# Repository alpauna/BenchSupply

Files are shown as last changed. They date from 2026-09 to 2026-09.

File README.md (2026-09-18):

# BenchSupply

A printed box for the bench supply that feeds the ECU and the VR test rig:
screw-down lid, 40 mm fan at one end, exhaust grid at the other, and a fused
IEC C14 inlet/switch module on the end wall beside that grid, its terminals
under a printed shield. A small **two-rail DC-DC module** has the long wall to
itself, fed from the 36 V supply inside — its fixed 5 V runs the
VR rig's Pico, its adjustable rail is a bench output.

**Forked from [`TritonECU/hardware/psu-enclosure`](../TritonECU/hardware/psu-enclosure) — this is the copy to grow.**
The two are still identical geometry: the DC-DC landed in **both**, because it
is part of the working box rather than speculative growth. `psu-enclosure` is
the version that stays printable; changes for the wider bench live here, so the
working enclosure is never in pieces. Diverge freely — from here on, expect to.

> **The supply this box was built around is being replaced.** It is going to a
> **toroidal transformer** and two isolated 2–60 V / 3 A channels, which is a
> different machine: two 2.9 kg toroids instead of one light switcher, ~100 W of
> heat instead of a warm box, and 5.8 A of mains with the inrush of two 350 VA
> transformers. **Do not print the tub from this file expecting it to hold that.**
> The reasoning is in [`docs/power-chain.md`](docs/power-chain.md), the control
> electronics and cooling in [`docs/control.md`](docs/control.md), and the
> schematics in [`design/`](design/);
> everything below still describes the box as drawn, which is correct for the
> old supply.

**This box contains mains wiring.** Read [Safety](#safety) before energising it.

## Room already in it

The box was sized generously on purpose. **The DC-DC is the first thing to take
any of that slack**, and it took less than it looks: 84 mm of the bay wall, and
depth only where its boss steps out.

| Where | Free space | Good for |
|---|---|---|
| Bay wall, between DC-DC and gland | **60 mm** of flat wall (x 106–166) | the largest unbroken panel span |
| Bay wall, past the gland | **90 mm** (x 194–282) | the mains has left this wall entirely — it is all low voltage now |
| Bay wall, END A end | 19 mm before the DC-DC | small stuff only |
| Front bay, volume | **50 mm** wide × 279 long, less the DC-DC's 84 | terminal blocks, DC distribution |
| Back bay | **34 mm** × 279, less the shield's 44 in the middle | **mains only** — keep it that way |
| Over the supply | 2 mm to the rim taper, 17 mm to the lid | nothing tall — raise `head` if you need a shelf |
| Fan-end plenum | 10 mm × 195 × 98 | the air path. Do not fill it |
| The lid | untouched | a flat 285 × 243 plate; panel-mount anything to it |
| END A | the LV gland only | the rest of that wall is the fan and the plenum |
| END B | exhaust grid only | the inlet left; the bay corners either side of the grid are free again |

**A buck module for the fan is no longer on that list** — the DC-DC covers the
role, but *not* on its adjustable rail. See [The fan is not a load for the
adjustable rail](#the-fan-is-not-a-load-for-the-adjustable-rail).

The honest constraint is **height**, not floor area. `head` is 2 mm, so there is
no usable layer above the supply until you raise it — and every mm you add there
adds a mm to the outside.

**The X growth cap has moved.** This was written against a 300 bed, which put
the ceiling at about 290 including the pads — right where the tub already sits.
The printer is now a **QIDI X-Plus 5: 320 × 320 × 300**, read from
`Qidi X-Plus 5 0.4 nozzle.json` in QIDIStudio 02.07.02.60. Against the tub's
current 294 × 243 that is **26 mm spare in X and 77 in Y**, so X is no longer
the axis that stops you — height still is, and it is the one axis the bed does
not help with.

```
                 TOP VIEW  (285 long)

     END A                                      END B
   +-------------------[ PLUG ]-----------------------+  <- BACK: mains only
   |                   [shield]        34 mm bay      |
   |--------------------------------------------------|
   |[FAN]                                       ######|
   |         power supply  266 x 153 x 77       ######|  <- exhaust grid
   |   intake -->  air over and under  -->  out ######|
   |--------------------------------------------------|
   |(LV)                               50 mm bay      |
   +--------[ DC-DC ]------------[GLAND]--------------+  <- FRONT: low voltage
             5 V + adj            36 V out
```

**Mains on the back wall, low voltage on the front.** The inlet is centred
because **a toroidal transformer sits either side of it**, so the primary leads
reach it from both without crossing. END B is nothing but exhaust grid now.

The mains lives on the **back wall only** — inlet centred, its terminals inside
a printed shield that stands on the floor. The front wall is all low voltage:
see [the inlet and its
shield](#the-inlet-is-on-the-back-wall--and-brought-a-shield).

## Dimensions

| | |
|---|---|
| External | **285 × 243 × 109** mm |
| Bed footprint, tub | **294 × 243** — the fan pad stands proud of END A, the plug pad off the back wall |
| Bed footprint, lid | 285 × 243 |
| Clear space for the supply | **279 × 156 × 79** (the 266 × 153 × 77 minimum, with room) |
| Wiring bays | **back 34 mm** (mains only), **front 50 mm** (low voltage, clear end to end) |

`openscad` echoes all of these on every render, so they follow the parameters
rather than this table. Re-read them after changing anything.

**The tub needs a genuine 300 × 300 bed**, with 5 mm to spare on each side in X.
Print it with a *skirt*, not a brim — a brim will not fit. If your printer
cannot reach 290, drop `clr_fan` from 10 to 6 and re-render; you lose plenum
depth at the fan and nothing else.

## Measure these before printing

The `.scad` is parametric but it cannot guess:

```
psu_l, psu_w, psu_h    the supply's real outside dimensions
standoff_xy            the supply's mounting-foot pattern
mod_cut_w/h, mod_depth the DC-DC module's body, and how far it stands behind
mod_flange, mod_lock_w its bezel lip and its snap locks
mod_boss               which is a DECISION, not a measurement — see below
```

The supply's dimensions default to the 266 × 153 × 77 minimum. **The foot
pattern has no default worth trusting** — there is no standard for it. The six
standoffs as shipped are *pads*: they hold the supply 4 mm off the floor so air
can get under it, and that is all they do. Measure the feet, edit
`standoff_xy`, then set `standoff_hole = true` to get M4 clearance holes with
head recesses on the underside of the floor.

The `mod_*` defaults are the module actually in hand — **64 × 38.5 × 25.4 behind
a 4 mm flange, with two 12.7 mm snap locks centred on the vertical edges.**
Measure yours. Every clearance on that wall that was tight enough to be worth
arithmetic is an `assert` in the `.scad`, so a wrong number stops the render
rather than the print.

## Bought parts

| Qty | Item | Notes |
|--:|---|---|
| 1 | **40 × 40 × 10 mm fan**, 12 V | 32 mm bolt centres, Ø3.5 holes — the WINSINN drawing |
| 1 | **IEC C14 inlet + rocker + fuse module** | BIQU 10 A 250 V; 58 × 48 face, 50 × 29 × 19 rear flange, M3 ears at 40 mm |
| 1 | 5 × 20 mm fuse | size it to the supply, not to the socket's 10 A rating |
| 10 | **M3 × 12 socket head** | lid |
| 4 | **M3 × 10 self-tapping** | fan, through its own Ø3.5 holes into the pad |
| 2 | **M3 × 12 self-tapping** | plug ears, into the 7 mm pad |
| 4 | M4 × 10 | supply feet, *once you have measured them* |
| 1 | **PG7 cable gland** or Ø12.5 rubber grommet | 36 V DC output, bay wall |
| — | 16–14 AWG wire + insulated spade terminals | the inlet module ships with a set |
| 4 | Stick-on rubber feet | the floor is flat by design |
| 1 | **DC-DC module, two rails** — fixed 5 V + LCD-set adjustable | 64 × 38.5 face, 25.4 deep, 4 mm flange, snap-lock mount. **40 V DC input rating** — confirmed, against a 36 V bus. See below |
| 1 | **Fuse + holder, 1–2 A**, inline | the 36 V tap to the DC-DC. *Not optional* — see below |
| 1 | **PG7 cable gland** or Ø12.5 grommet | low-voltage output, END A wall |
| 1 | **Schottky, 1 A** (1N5819 or similar) | in the 5 V feed to the Pico's `VSYS` |
| — | 20–22 AWG wire, **two colours** | the 5 V pair and the adjustable pair, kept tellable apart |
| 2 | **M3 × 10 self-tapping** | the mains shield, into its two floor posts |

## Printed parts

| Qty | Part | Orientation |
|--:|---|---|
| 1 | `tub` | **floor down**, open side up |
| 1 | `lid` | **outer face down** — see below |
| 1 | `shield` | **on its back** — the flat face that carries the wire slot, down on the bed |
| 1 | `psu5_shell` | **face down** — the grid face flat on the bed, so no wall overhangs |

**Print the lid upside down, outer face on the bed.** Modelled ribs-down as it
sits on the box, so flipping it makes every rib and the locating ring grow
*upward*. Nothing then overhangs except a 1.5 mm annular bridge over each screw
counterbore, which any printer manages. Printed the other way up, four ribs and
a 250 mm ring are all overhang.

**PETG or ABS, not PLA.** This one is not about stiffness — it is that the box
holds a warm supply and a mains connection, and PLA softens at temperatures a
loaded supply reaches in a closed box.

Walls are 3 mm, **the floor is 6** — see below. 3 perimeters and 25 % infill is
plenty. The lid wants **4 perimeters** so the screw counterbores have solid
material around them.

### The floor is doubled, and not for strength

5.8 kg of toroidal transformer is not a lot of load — even a 3 mm floor only
sees **2.6 MPa** against PETG's ~50 MPa yield. Stress was never the problem.
**Deflection is:**

```
   t          D   deflection    stress
  3mm      5357       2.13 mm    2.62 MPa
  6mm     42857       0.27 mm    0.65 MPa
  8mm    101587       0.11 mm    0.37 MPa
```

A 3 mm floor bows **2.1 mm** under its own occupants, and a box standing on four
rubber feet rocks on that. Worse, PETG creeps, so whatever it bows settles in
permanently — and a box shedding ~100 W runs warm, which speeds creep up.

Doubling to 6 mm is **8× the stiffness** (t³) and a quarter of the stress
(1/t²), for 0.27 mm. It costs ~200 cm³ of envelope — call it 130–250 g
depending on infill — and 3 mm of height. [`docs/calc/floor.py`](docs/calc/floor.py)
has the arithmetic and a sensitivity sweep, because printed PETG's modulus is
not a datasheet number.

**What 6 mm does not fix: the bolt.** Each toroid still hangs off one central
screw, and a screw in plastic is a bearing problem, not a bending one. **Put a
steel spreader under the floor** — a large washer at minimum, better a plate.

## How it is put together

### The lid seat is a rim band, not corner posts

With 3 mm of clearance beside the supply there is nowhere to put a corner post —
it would land inside the supply. So the screws go into a band that thickens the
wall inward around the whole top rim, sitting **entirely above the supply**
where the volume is free anyway. It costs 17 mm of height and no floor area.

The band's underside is a 45° taper (`rim_taper = rim_w`, keep them equal), so
it prints with no support and leaves no drooping ledge over the supply. Its
inner face is the rabbet the lid's locating ring drops into, which is what stops
the lid sliding and closes the dust gap.

Ten M3s: four along each long wall, one at each end.

### The fan mounts outside

Inside would cost 10 mm of a 10 mm plenum, and the supply is only 10 mm away.
The pad on the outside also gives the M3s **8 mm of plastic** to cut into
instead of 3.

**Mount it as an intake** — airflow arrow and label pointing *into* the box. Air
enters at END A, splits between the 4 mm gap under the supply and the space over
it, and leaves through the grid at END B. Blowing the length of the supply is
the whole reason the fan and grid are on opposite ends rather than opposite
sides. Run the fan off the supply's own DC output if the voltage matches, or off
a small fixed buck of its own — **not** off the DC-DC's adjustable rail, for the
reason in [The fan is not a load for the adjustable
rail](#the-fan-is-not-a-load-for-the-adjustable-rail).

### The grid is diamonds, not squares

A square hole in a vertical wall has a flat top edge that has to bridge. A
diamond has an apex, so every one of the 78 holes is self-supporting and nothing
droops into the airstream.

### The bay is still why things fit — just not the plug any more

The bay was originally sized by the inlet: its rear flange stands **19 mm**
proud of the panel, the spade terminals and their boots add more, and none of
that can happen on the wall the supply is pressed against. So a channel ran down
one long side.

**The inlet has since moved to the back wall**, and the front bay stayed — two other
things now need it. The DC-DC is 25.4 mm deep behind its panel, and the mains
shield is 44 mm wide. The shield is the binding one: 29 mm of flange, clearance
for booted spades either side, a wall each side, and a 39 mm bay cannot hold it
at any sane wall thickness.

At **50 mm** the shield fits with 3 mm a side, and the DC-DC gets 24.6 mm behind
it on a flat wall — so `mod_boss` went to **0** and the bump on the outside of
that wall disappeared. The box grew 11 mm in Y and lost a 12 mm boss, and the
plug pad moved from the Y face to the X face: **the bed footprint went from
290 × 213 to 294 × 212 at that point, which was no change worth the name.**
(The back bay has since taken it to 294 × 243 — see the inlet section.)

`gland_x` is a parameter. Slide it along the wall to land beside the supply's
own DC output terminals. The shield no longer competes for this bay at all —
it moved to the back with the inlet — so the front wall is clear end to end.

## The inlet is on the back wall — and brought a shield

### The back wall was blank because it had no depth

That wall had nothing on it, which is exactly why it was the one to use — and
exactly why it could not be used as drawn. The supply sat **3 mm** behind it,
and 12 mm of intruding flange plus 12 mm of booted terminals does not go in
3 mm. `bay_back` is what buys the room: **34 mm**, which leaves 2.5 mm between
the shield and the supply.

**It is cheaper on this wall than it was at END B.** There the shield's 44 mm
*width* had to fit across the bay, so the bay had to be 50. On a long wall the
width runs along the wall, which is free, and only the 31.5 mm of depth costs
anything. The box went 212 → **243** in Y for it, and the bed footprint to
294 × 243 — comfortable on a 320 bed.

What it buys back: the mains now has a wall to itself, the front wall is all
low voltage — the DC-DC's screen and knob, the outputs — and **END B is nothing
but exhaust grid**, which is better for the air than having a shield parked in
the bay at the hot end.

`plug_x` is centred, and stays centred: **a toroid sits either side of it.**

### And it sits low, which is the shield's doing

The shield **stands on the enclosure floor** and uses that floor as the fourth
side of its wire slot. That only works if the terminals are near the floor, so
`plug_z` is **36**, putting the flange between z 11 and 61 and leaving 8 mm of
shield underneath for the wires to turn in.

It is still mounted **58 mm axis vertical**, so the rocker is at the top and the
fuse drawer pulls out below it. The pad is a slab on the *outside* of the back
wall, so `plug_pad_w` has to stay within the wall's length or it hangs in
mid-air with nothing behind it — the `.scad` asserts that, though with 285 mm of
wall and a 54 mm pad there is no danger.

### The shield: two open faces, and a slot that is open at the bottom

The inlet's spade terminals are exposed mains. With the lid off they are a
finger away. The shield covers them.

**They are no longer the only exposed mains.** The 5 V control module is an
open-frame board — live AC terminals and a live primary side on a bare PCB. It
needs the same treatment; see [`docs/control.md`](docs/control.md#it-is-open-frame--so-it-needs-a-cover-too).

It is a cup with **two open faces**: the one against the END B wall, where the
inlet comes through, and the **bottom**, where it stands on the floor.

**The wire slot is the whole point of the shape.** The three spades are crimped
and booted *before* the shield goes anywhere near them, so the wires cannot be
threaded through a closed hole — a closed hole would mean stripping the
terminals off again to fit the cover. So the slot runs off the bottom edge of
the back wall: **three of its sides are printed into the shield, and the fourth
is the enclosure floor** once the shield is screwed down. Lay the booted wires
in, drop the shield over them, put two screws in.

The slot is **26 × 14**, which takes three booted spades side by side.

### Assembly order matters now

**Fit the inlet and drive its two ear screws before the shield goes on.** The
shield covers the back of the inlet completely; once it is down, those screws
are unreachable without taking it off again. Same for the spade terminals —
crimp, boot and seat them all first.

### Print it on its back

Laid with the slotted back face on the bed, every other wall of the shield is
perpendicular to the bed. **There is not one overhang in the part** — no
supports, no bridges, and the slot comes out as a clean rectangular notch rather
than a sagging hole.

## The second supply — a DC-DC module, not a second mains supply

The box gained a second output stage: a two-rail DC-DC with an LCD, panel
mounted at the END A end of the bay. **It is fed from the 36 V supply already in
the box, not from the mains.** That is what makes it a cheap addition — no
second inlet, no second cord, and no more live terminals in a box that already
has a set. Everything it does still sits downstream of the C14's fuse.

| rail | what it is for |
|---|---|
| **fixed 5 V** | the VR rig's Pico, and the DM542's `PUL+ / DIR+ / ENA+` commons |
| **adjustable** | set from the LCD; a bench rail, out through the same gland |

### 40 V in, on a 36 V bus — which makes it the weakest part on that bus

**The module is rated 40 V DC in.** Against 36 V that is 4 V of headroom, about
11 %, and in steady state it is fine: an open-frame supply regulates to a
percent or so and never goes near the ceiling. (Worth saying because most
modules this size stop at 32 V, which this supply would destroy on the first
switch-on. This one clears it.)

What the rating changes is *which part fails first*. The DM542 is rated **50 V**.
The DC-DC is rated **40**. **The lowest-rated thing on the 36 V bus is now the
supply the Pico runs on** — so an excursion that used to threaten only the
driver now takes out the 5 V rail first, and the step generator with it.

That excursion is already documented: [ramp the
decelerations](../TritonECU/hardware/vr-test-rig/BOM.md#ramp-the-decelerations--capacitance-cannot-fix-a-hard-stop).
A switching supply cannot sink current, so a hard stop dumps the wheel's energy
into whatever capacitance is on the bus and drives it to 64–120 V. That ramp was
load-bearing before. It is more so now, against a ceiling 10 V lower.

Two things follow:

- **Do not touch the supply's V-ADJ trimmer.** Open-frame supplies commonly trim
  ±10 %, and +10 % of 36 is **39.6 V** — 0.4 V from the module's absolute
  maximum, before any transient at all.
- The 1000 µF at the driver's `V+` is now insurance for the DC-DC as well as for
  the driver. Fit it.

#### And a TVS cannot cover the gap

The reflex is to clamp the bus. It does not work here, and the reason is
arithmetic rather than taste: the part would have to stand off 36 V without
conducting **and** clamp below 40 V, and nothing does both. The lowest standard
device that stands off 36 V is an `SMBJ36A` — breakdown **40.0–44.2 V**,
clamping at **58.1 V**. Its breakdown tolerance alone is wider than the whole
4 V margin: at one end of the spread it begins conducting at the module's
ceiling, and it does not clamp hard until 18 V past it.

The window between 36 V working and 40 V absolute maximum is too narrow for a
transient suppressor to live in. **The ramp is the mitigation; there is no
component to buy instead.**

### Fuse the tap

The 36 V supply will put **10 A into a fault** and has no idea it is a fault.
Put a **1–2 A fuse in the tap**, at the supply's terminal end so it protects the
wire and not just the module. The C14's fuse is sized for the whole supply and
will never notice a shorted DC-DC — which is a fault inside a plastic box.

### The Pico goes on `VSYS`, not `VBUS`

The Pico's **`VBUS` pin is the USB connector's 5 V, directly.** Feeding it means
back-feeding the host's USB port. Use **`VSYS` (pin 39)**, with GND on pin 38 —
that is what the datasheet provides for exactly this. USB reaches `VSYS` through
the on-board Schottky `D1`, so a cable can stay plugged in for programming: `D1`
reverse-blocks and nothing flows back into the port.

Put a **Schottky in the feed** as well, so the module is protected in the other
direction too. 5 V less the drop lands `VSYS` near 4.7 V, comfortably inside its
1.8–5.5 V range.

The part that is an *improvement* rather than a change: `PUL+ / DIR+ / ENA+`
come off this same 5 V rail. [The VR rig BOM](../TritonECU/hardware/vr-test-rig/BOM.md) used to
take them from the Pico's `VBUS`, which meant **the driver's opto commons died
the moment the USB cable was unplugged.** On this rail they do not.

The module's 5 V return, the Pico's GND and the 2N7002 sources are one node.
Run the 5 V and its return out as a **pair**.

### Star the ground — it is no longer floating

The optos were never isolating the Pico from the motor supply in the first
place: `PUL+` and `PUL−` are both in the Pico's domain and the barrier is inside
the driver. What changes is the **reference**. A non-isolated buck ties the
Pico's ground to the 36 V supply's negative, which is also the DM542's return —
and 2 A/phase of chopper current flows in that return.

So take the module's input **from the supply's own output terminals**, not
daisy-chained off the DM542's `V+ / V−` screws. Then the motor's return current
never flows through a conductor the Pico's ground shares, and the ripple stays
where it belongs.

One consequence worth knowing about: with the Pico's ground tied to the supply
negative, a USB cable to a PC now joins the PC's ground to it as well. That path
did not exist before.

### The fan is not a load for the adjustable rail

Tempting — the fan wants 12 V, this page used to hand-wave "a small buck module
in the bay", and there is now a rail in the bay that can be set to 12.
**Don't.** It would put the cooling on a knob, in a box whose airflow depends
entirely on that fan and which holds a warm supply and a mains connection. Give
the fan its own fixed source and leave the adjustable rail free.

### Label the two pairs at the gland

Two wire pairs leave the same gland and one of them can be at 30 V. **Two
colours, and a label at both ends.** Swapping them puts the adjustable rail on
the Pico's `VSYS`.

### It sits in still air

The fan blows END A to END B *over and under the supply*; the bay is off to one
side and barely sees it. At the load this rail was added for — a Pico and three
optos, call it 100 mA at 5 V, well under a watt — that does not matter. Start
pulling amps from the adjustable rail and the module wants a heatsink, because
the bay will not cool it.

## How the DC-DC is mounted

### It hangs on its own snap locks

Two tapered locks, one on each **vertical edge** of the cutout, 12.7 mm long,
centred. They start about 1 mm behind the bezel and taper back 3, so they grip a
panel **1 to 4 mm thick**. A 3 mm wall is right at the far end of that taper —
a loose grip on a module standing 25 mm off the panel — so the panel is
**thinned to 2 mm** over a patch reaching 6 mm past the cutout all round.

That relief is cut on the **inside** face. The outside stays flat, so the bezel
lands on plain wall and none of it shows.

Nothing else holds the module: no screws, no brackets. The cutout's left and
right edges are the only surfaces carrying it, so keep them clean and do not put
anything else on them. Printed floor-down they are vertical walls and come out
crisp — but test-fit the module before you wire anything to it.

### The panel is flat — the boss is gone

It was not always. When the inlet shared this wall the bay was 39 mm, the module
is 25.4 deep, and that left 13.6 mm for its terminals and the bend in the wire —
not enough if they exit straight back, which on these modules they usually do.
The panel sat on a boss that stepped **12 mm outward** to buy 25.6 mm.

Moving the inlet to END B forced the bay to 50 for the shield, and **50 − 25.4
is 24.6 mm on a flat wall** — as much as the boss ever bought. So `mod_boss` is
**0**, the bump is gone, and the long wall is flat from end to end.

Raise `mod_boss` again if you ever narrow the bay; the geometry is still there
and still drafted at 45°. The render asserts you have left enough room either
way.

### Why END A, and why the output leaves on the end wall

Three things now share the bay wall, and the order is deliberate: **low voltage
at END A, mains in the middle, 36 V DC at END B.** The DC-DC's output gland is
on the **END A wall**, not the bay wall, so the 5 V and adjustable pairs never
run the length of the bay toward END B, where the mains now is.

`mod_x` slides the module along the wall as `gland_x` does — and the `.scad`
asserts it clears both the gland and the ends, so a bad value stops the render.

## Safety

The box is plastic, so there is nothing to bond to earth — but the C14's earth
pin still has to go somewhere. **Run it to the supply's earth terminal.** Do not
leave it unconnected because the enclosure is non-conductive; the supply's
chassis and its output reference need it.

- The lid screws are the only thing between a finger and 120 V. Fit all ten.
- Fuse for the *supply*, not for the socket. The inlet module is rated 10 A;
  that is a ceiling, not a recommendation.
- Use the insulated spade terminals the inlet module ships with, fully seated.
- Fit the cable gland or grommet before pulling the DC output wires through. A
  bare printed hole will cut insulation over time, and the layer lines make it
  worse than a drilled one.
- Strain-relieve the mains wiring inside the bay so a tug on the cord cannot
  reach the terminals.
- **Fit the shield.** It is the only thing between a finger and the inlet's
  terminals once the lid is off, and it is two screws. Fit the inlet and drive
  its ear screws *first* — the shield covers them.
- **Fuse the DC-DC's 36 V tap at 1–2 A.** A shorted module on a 10 A supply is
  an ignition source, and the C14 fuse is far too big to see it.
- Keep the DC-DC's wiring at the END A end of the bay, clear of the inlet's
  spade terminals. That separation is why the module and its gland are where
  they are; do not undo it by routing the low-voltage pairs past the plug.

## Rendering

```bash
./render.sh          # all three parts to stl/
```

Or one at a time:

```bash
openscad -D 'part="tub"' bench_supply.scad
openscad -D 'part="lid"' bench_supply.scad
openscad -D 'part="shield"' bench_supply.scad
```

`part = "assembly"` (the default when you open the file) shows the tub, the lid
in place, the shield in **red**, and **ghosts** of the supply, the fan, the
DC-DC and the inlet. The inlet ghost is the one to look at: its terminal block
is what the shield has to swallow, and what sets the bay width.

STL export is not byte-deterministic — rendering the same unchanged file twice
produces different files. **`bench_supply.scad` is the source of truth**; the
STLs are a convenience so the parts can be printed without installing OpenSCAD.
Re-run `render.sh` after any change and do not read anything into the diff.

## Parameters worth knowing

| Parameter | Default | What it moves |
|---|--:|---|
| `psu_l/w/h` | 266/153/77 | everything — **measure yours** |
| `standoff_xy`, `standoff_hole` | pads, off | the supply's foot pattern |
| `clr_fan` | 10 | plenum depth at the fan end, and total length |
| `bay_w` | 50 | wiring channel; the **shield** needs most of it now |
| `rim_w`, `rim_taper` | 6, 6 | lid seat. **Keep them equal** — that is the 45° |
| `boss_d` | 9 | lid screw engagement. Heat-set inserts? 7 is enough |
| `lid_screw` | 2.6 | M3 self-tapping pilot. Heat-set M3 insert: **4.2** |
| `fan_guard` | true | concentric webs over the fan bore |
| `plug_x`, `plug_z` | **centre**, 36 | where the inlet lands on the back wall. Centred for the toroids either side; low so the shield reaches the floor |
| `gland_x` | −105 | where the 36 V output leaves the bay wall |
| `bay_w` | **50** | front bay — low voltage. Set by the DC-DC now |
| `bay_back` | **34** | back bay — mains only. Set by the shield's depth |
| `sh_clr`, `sh_wall` | 5, 2.5 | shield clearance round the terminals, and its wall |
| `sh_notch_w/h` | 26, 14 | the wire slot. Its fourth side is the floor |
| `sh_tab_z` | 20 | screw tabs, high enough to clear the slot |
| `grid_pitch`, `grid_sq` | 10, 6 | exhaust open area |
| `mod_cut_w/h`, `mod_depth` | 64/38.5, 25.4 | the DC-DC's body — **measure yours** |
| `mod_boss` | **0** | how far the DC-DC's panel steps out. 0 = flat wall; changes the box |
| `mod_panel_t` | 2.0 | panel at the cutout. The snap locks grip 1–4 |
| `mod_x` | 64 | where the DC-DC lands along the bay wall |
| `mod_relief_m` | 6 | how far the thinned panel reaches past the cutout |

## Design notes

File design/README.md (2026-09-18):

# design

Schematics and BOMs. The reasoning behind every value is in
[`../docs/power-chain.md`](../docs/power-chain.md) and
[`../docs/control.md`](../docs/control.md); the scripts in `../docs/calc/`
reproduce the numbers.

| board | qty | schematic | BOM |
|---|--:|---|---|
| Mains entry, distribution, soft start | 1 | [`schematic-mains.txt`](schematic-mains.txt) | [`bom-mains.csv`](bom-mains.csv) |
| Rectifier and bulk | **2** | [`schematic-rectifier.txt`](schematic-rectifier.txt) | [`bom-rectifier.csv`](bom-rectifier.csv) |
| LT8705 converter | **2** | [`schematic-converter.txt`](schematic-converter.txt) | [`bom-converter.csv`](bom-converter.csv) |
| Control - Pico, fans, sensors, UI | 1 | [`schematic-control.txt`](schematic-control.txt) | [`bom-control.csv`](bom-control.csv) |

One mains board. One rectifier and one converter **per channel**.

## Before you draw any of it

**The LT8705 pin names in the converter schematic are functional, not
transcribed.** Check them and the pin numbers against the datasheet. That
document is the design intent.

**Confirm Qg on whichever FET you buy.** It is the binding parameter — at 60 V
switching loss beats conduction loss, so a 10 mΩ part carrying 150 nC loses to
a 25 mΩ part carrying 40 nC — and it is the number least reliably quoted in
distributor listings.

**Verify the ADG714 powers up with all switches open.** That is the fail-safe
direction: switches open is 2 V out, and it has to hold when the isolated side
is unpowered, in reset, or being reflashed.

## Three things in here that are structural, not preferences

Each survives a component failure, a firmware hang, or a reflash. None of them
should be "simplified" later without understanding what it is buying.

**The fixed divider branch sets 2 V and the switches only add.** Switches open —
unpowered, in reset, mid-reflash — is minimum output. Wired the other way round,
every one of those states commands 60 V into whatever is connected.

**`RLY_SOFT` is a one-shot, not a level.** It drops out by itself whether or not
`RLY_MAIN` closed, so the 10 Ω soft-start resistor can only ever be in circuit
for one monostable period. Without that, a relay that fails to close leaves it
at 85 W indefinitely.

**TS1 sits in parallel with fan 1's drive FET.** All three fans are staged by
the Pico, and a thermostat closes at 65 °C regardless — so a box shedding 108 W
with no fans because the Pico is halted, or because someone is reflashing it,
cannot happen. Hardwiring fan 1 on would also prevent it, and would throw away
useful control to do so.

## Where the optocouplers live

**On the converter boards, not on the control board.** Every signal leaving the
control board is Pico-referenced, including the LED drive going out and the
phototransistor collector coming back — the isolation happens at the far end.

Put them on the control board instead and it would carry **three** isolated
domains — Pico, channel A, channel B — with barrier slots between them. There is
no reason to.

## What is not here yet

Nothing. All four boards are drawn. What remains before layout is the
[layout spec](../docs/) — net classes, trace widths, hot-loop targets — and
confirming the three items above.

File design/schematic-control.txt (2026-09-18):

BENCH SUPPLY - CONTROL BOARD
Pico, the barrier drive, fan staging, sensors, relay sequencing
===============================================================================

  ** THE OPTOCOUPLERS ARE NOT ON THIS BOARD. **

  They live on the converter boards, one set per channel. That is deliberate
  and it is what keeps this board simple: every signal leaving here is
  referenced to the Pico's ground, including the LED drive going out and the
  phototransistor collector coming back. The isolation happens over there.

  Put the optos here instead and this board would carry THREE isolated
  domains - Pico, channel A, channel B - with barrier slots between them.
  There is no reason to.

  So: ONE ground domain on this board. The 5 V module feeds it, and the
  module's own transformer is what isolates the whole thing from mains.

1. GPIO BUDGET - CHECK THIS BEFORE ADDING ANYTHING
--------------------------------------------------

  SPI0 to channel A: SCK MOSI MISO CS_SW CS_AD     5
  SPI1 to channel B: SCK MOSI MISO CS_SW CS_AD     5
  RLY_MAIN drive x2                                2
  NE556 trigger x2 (the RLY_SOFT one-shots)        2
  fan 1, fan 2, fan 3 drive                        3
  1-Wire bus (3 sensors)                           1
  display, I2C                                     2
  encoder A: A B push                              3
  encoder B: A B push                              3
  --------------------------------------------------
  TOTAL                                           26   of 26. NONE SPARE.

  Driving fan 1 costs the last pin.

1a. THE EXPANSION ROUTE - MCP23017, AND IT COSTS NO PINS
--------------------------------------------------------

  The display is already I2C and already costs 2 pins. An MCP23017 at a
  different address on the SAME BUS costs ZERO additional GPIOs and brings
  16 more I/O. It is also the part already used in TritonECU at 0x20.

  Move the slow set-and-forget outputs onto it:

      RLY_MAIN x2               2
      NE556 triggers x2         2
      fan 1 / 2 / 3             3
      --------------------------
                                7   freed

      GPIO      26 used -> 19 used, 7 spare
      expander  7 of 16 used, 9 left over

  ** DO NOT PUT THE ENCODERS ON IT. **
  Quadrature needs prompt reads. An expander behind a bus - or behind an
  interrupt you have to service - turns a knob into a source of missed
  counts. Encoders stay on real pins. Slow outputs are what an expander is
  for; a rotating shaft is not.

  An SPI expander (MCP23S17) also works and can share SPI0's SCK/MOSI/MISO
  with the opto drive - the GPIO drives the LED and the expander input, and
  the expander tristates MISO when deselected. But it costs one pin for CS
  AND inherits the bus speed, which is a few kHz because of the optos.
  The I2C route is strictly better here.

  Failure mode, checked rather than assumed. A dead expander or a stuck bus
  loses control of both relays and fans:

      relays -> the box does not come on. Benign, same as a dead Pico.
      fans   -> TS1 closes at 65 C and runs fan 1 regardless.

  The thermostat that made fan 1 safe to software-control is the same thing
  that makes it safe to put behind an expander. That was not why it was
  added, but it is a real consequence - the expander adds a dependency, not
  a hazard.

  Two things buy room if it gets tighter:
    - share one SPI across both channels, picking with CS. Costs 10 mA of
      GPIO drive into two opto LEDs at once instead of 5 - inside the
      RP2040's 12 mA, but with nothing left.
    - one encoder plus a channel-select button instead of two.

  Keeping SPI0 and SPI1 separate is worth the pins: the channels are
  isolated from each other, and a shared clock means one GPIO driving LEDs
  in two different isolated domains.

2. POWER
--------

   from the 5 V module          +5V rail
   (back wall, always on        o---+-------+--------+--------+--------+
    with the rocker)                |       |        |        |        |
        +5V o--------+----------- Pico    fans    relay    opto     1-Wire
                     |            VSYS    (3)     coils    LEDs     pull-up
        GND o--------+                     |       (4)
                     |                     |
                    ===  470u + 100n     ** fans get their own feed or their
                     |                      own decoupling: commutation spikes
                    GND                     land on the rail the ADC reads
                                            millivolts of shunt signal from **

   ** VSYS, PIN 39. NOT VBUS. **
   VBUS is the USB connector's 5 V with nothing in between, so driving it
   back-feeds whatever host is plugged in. USB reaches VSYS through the
   on-board Schottky D1, so a cable can stay connected for programming while
   the module's 5 V holds VSYS up. Ground on pin 38.

   Budget (docs/calc/control.py):
     Pico 100 mA + 3 fans 600 + opto LEDs 50 + 4 relay coils 320 = 1070 mA
     against the module's 3 A. 2.8x.

3. THE BARRIER DRIVE - LOGIC OUT, LOGIC BACK
--------------------------------------------

   Per channel, to a 6-pin header. All Pico-referenced.

     GP -> SCK    ---->|  to OK1 LED anode on the converter board
     GP -> MOSI   ---->|  to OK2
     GP -> CS_SW  ---->|  to OK3
     GP -> CS_AD  ---->|  to OK4
     GP <- MISO   <----|  from OK5 phototransistor collector
     GND ------------->|

   The 330R LED resistors are on the converter board with their optos.
   ** The MISO pull-up (10k to 3V3) belongs HERE **, on the Pico side -
   it is the only one of the five that is not in an isolated domain.

   Clock at a few kHz. A 10k pull-up and a phototransistor make edges tens
   of microseconds long, so 10 bits takes single-digit milliseconds. That is
   invisible to someone turning a knob, and trying to run it at SPI speeds
   will simply not work.

4. FANS - ALL THREE STAGED, WITH A BACKSTOP THAT IS NOT FIRMWARE
----------------------------------------------------------------

   FAN1 o----+-------[ AO3400 on a 2N7002 board ]------- GND
             |              gate <- GP, 220R + 10k pulldown
            D1             |
             |             +--------[ TS1 ]------------- GND
             |                    60-70 C thermostat
             |                    normally open
             |
   FAN2 o----+-------[ AO3400 on a 2N7002 board ]------- GND
            D2
   FAN3 o----+-------[ AO3400 on a 2N7002 board ]------- GND
            D3

   All three are Pico-staged on temperature:

     fan 1   on 35 C   off 30 C
     fan 2   on 45 C   off 40 C
     fan 3   on 55 C   off 48 C
     TS1     closes ~65 C, opens ~55 C   HARDWARE. No firmware in the path.

   ** TS1 IS WHY FAN 1 CAN BE SOFTWARE-CONTROLLED. **
   A bimetallic thermostat in PARALLEL with fan 1's drive FET. In normal
   operation the Pico stages fan 1 like the others and TS1 never closes -
   it sits above fan 3's threshold on purpose. If the Pico is halted, hung
   or mid-reflash, the heatsink climbs to 65 C and TS1 runs the fan
   directly.

   That keeps the staging as specified AND satisfies "cooling must not
   depend on firmware". One part, and the dangerous case has no software
   in it at all. Hardwiring fan 1 permanently on would also satisfy the
   second requirement - and throw away the first for no reason.

   AO3400, not the 2N7002 the boards ship with: a 200 mA fan is 1.7x a
   2N7002's 115 mA rating, and 2-3x that at startup. Same SOT-23 pinout
   (G-S-D), same 220R and 10k - a transistor swap, not a redesign.

   Flyback diode on EVERY fan. The driver board does not carry one, and it
   matters more with an AO3400's 30 V than the 2N7002's 60.

   Mount TS1 on the same heatsink as the 1-Wire probe that drives the
   staging. They are watching for the same thing; TS1 just does not need
   anyone to be listening.

5. RELAY SEQUENCING - TWO LINES PER CHANNEL, NOT THREE
------------------------------------------------------

   GP -> RLY_MAIN_A  --> FET on the mains board -> RLY_MAIN coil
   GP -> TRIG_A      --> NE556 trigger, active low

   Same for B.

   The Pico does NOT drive RLY_SOFT. It triggers a monostable that does, and
   that monostable drops the relay out by itself whether or not anything
   else worked. See schematic-mains.txt section 3.

   Sequence per channel:  TRIG -> (RLY_SOFT closes, inrush limited by 10R)
                          +250 ms -> RLY_MAIN closes, R bypassed
                          +300 ms -> RLY_SOFT drops out on its own

   Stagger the two channels ~200 ms apart. Firing both together makes the
   inrush peaks add - 34 A instead of 17 - and the Pico is triggering them
   anyway, so it costs one line of firmware.

   A 3.3 V GPIO pulled low triggers a 5 V 556 correctly: its threshold is
   1/3 Vcc = 1.67 V. No level shifter needed on the trigger.

6. TEMPERATURE - 1-WIRE, ONE PIN FOR ALL OF IT
----------------------------------------------

   3V3 o---[ 4k7 ]---+---o DQ ---- GP
                     |
                     +---- DS18B20 probe 1 : pass-element heatsink, channel A
                     +---- DS18B20 probe 2 : pass-element heatsink, channel B
                     +---- DS18B20 probe 3 : intake air

   Stainless probes, and the packaging is the point: they are electrically
   isolated BY CONSTRUCTION. The heatsinks are tied to their own channels'
   grounds, so channel A's sink and channel B's sink sit up to 60 V apart
   once the outputs are stacked. A metal-cased sensor bolted to each, both
   wired back here, would BRIDGE THE TWO CHANNELS.

   (Good for a 60 V heatsink. Not safety insulation - not against mains.)

   The heatsink probe drives the staging; it leads everything else by a long
   way. The intake probe goes in the fan stream and away from any heatsink
   or it reads its own self-heating.

     fan 1   on 35 C   off 30 C
     fan 2   on 45 C   off 40 C
     fan 3   on 55 C   off 48 C

   Thresholds with hysteresis, NOT "temperature still rising" - a derivative
   trigger fires on every load step and lid opening and is unloggable to
   tune. And a FAILED READ - CRC error, missing sensor, shorted bus - must
   stage UP. Treat it as hot. Not as cold, and not as hold-the-last-value.

7. USER INTERFACE
-----------------

   Display   I2C, 2 pins, on a header. SSD1306-class or similar.
   Encoders  one per channel: A, B, push. 3 pins each.

   Both are OPEN - see docs/control.md. What is fixed is that they cost 8
   GPIOs between them and there is only one spare.

8. WHAT IS DELIBERATELY NOT ON THIS BOARD
-----------------------------------------

  * No optocouplers. They are on the converter boards - see the top.
  * No mains. Not one net on this board is above 5 V.
  * No relay coils or their FETs. Those are on the mains board, next to
    the contacts they switch.
  * No current sensing. The INAs are on the converter boards, at the shunts,
    and their readings arrive as ADC counts over the barrier.

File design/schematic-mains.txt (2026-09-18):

BENCH SUPPLY - MAINS ENTRY, DISTRIBUTION AND SOFT START
120 VAC in, two toroid primaries out, plus the 5 V control module
===============================================================================

  Lives on the BACK WALL behind the printed shield. This is the only mains
  in the box. Everything downstream of the transformers is floating.

  The inlet feeds THREE loads, which is why it is a distribution point and
  not just a socket: toroid A, toroid B, and the 5 V control module.

1. ENTRY AND DISTRIBUTION
-------------------------

   IEC C14 inlet
   with rocker + fuse drawer
        L o-----/ /-----+-------------------+-------------------+
                F0      |                   |                   |
             10 A T    F1                  F2                  F3
             250 V    5 A T               5 A T               1 A T
             (in the  250 V               250 V               250 V
              drawer)  |                   |                   |
                       |                   |                   |
                    [soft start A]      [soft start B]         |
                       |                   |                   |
                       |                   |                   |
        N o------------+---+---------------+---+---------------+---+
                           |                   |                   |
                       toroid A            toroid B            5 V module
                       primary             primary             ACL / ACN
                       (brown 18AWG)                           (always on)

        E o--------------------+--> supply earth terminals, star point
                               +--> any exposed metalwork
                                    The enclosure is plastic, but the C14's
                                    earth pin still has to go somewhere.

  All three are 5 x 20 mm CARTRIDGE, 250 V. Mains cannot use blade fuses.
  Values allow for derating - a cartridge runs at ~89% of rating at the 45 C
  inside this box:

      F0  10 A T   carries 5.99 A   both channels at full output at once
      F1  5 A T    carries 2.92 A   4 A derates to 3.6 and blows on a warm day
      F2  5 A T    carries 2.92 A
      F3  1 A T    carries 0.16 A   the 5 V module, 5.6x margin

  F0 is also the inlet module's own 10 A ceiling, so there is no room above
  it. It only binds with both channels at full output simultaneously, and
  each leg has its own fuse - but it is the reason not to grow the load.

  ** The 5 V module is ALWAYS ON with the rocker, ahead of any relay. **
  It has to be: it powers the Pico that closes the relays, and the fan that
  runs whenever the box is powered.

2. SOFT START - TWO STAGE, ONE PER TRANSFORMER
---------------------------------------------

                    RLY_SOFT           R 10R 20W
       from F1 o--+-----/ o------------[\/\/\]------+-----o to primary
                  |                                 |
                  |          RLY_MAIN               |
                  +-------------/ o-----------------+

  Two parallel paths. Soft first, then main.

  Sequence:
    1. rocker on            -> 5 V module up, Pico boots, fan 1 runs
    2. RLY_SOFT closes      -> primary energises THROUGH R, inrush limited
    3. ~250 ms later
       RLY_MAIN closes      -> R bypassed, running normally
    4. RLY_SOFT drops out   -> R out of circuit entirely

  Without R, a 350 VA toroid's inrush is 10-100x its 2.92 A rating:

      10x ->   29 A      30x ->   88 A      100x ->  292 A

  depending on where in the cycle you switch and on the residual flux. That
  is what welds switch contacts and trips breakers. With 10 R:

       R     peak inrush   W while in circuit   J over 300 ms
     4.7R          36 A                 40 W            12 J
    10.0R          17 A                 85 W            26 J
    22.0R           8 A                187 W            56 J

3. RLY_SOFT IS A ONE-SHOT, AND THAT IS THE WHOLE SAFETY ARGUMENT
----------------------------------------------------------------

  ** RLY_SOFT IS DRIVEN BY A 555 MONOSTABLE, ~300 ms. NOT BY A LEVEL. **

  It drops out by itself whether or not anything else worked:

    RLY_MAIN closes in time -> R bypassed, running. Normal.
    RLY_MAIN never closes   -> RLY_SOFT drops at 300 ms and the box is
                               simply OFF. Nothing burns. Nothing to detect,
                               nothing to recover from.

  The resistor can only ever be in circuit for one monostable period. Worst
  case is 85 W x 0.3 s = 26 J per attempt, and even retriggered continuously
  that is a warm 20 W wirewound rather than a fire.

  This is why the two-stage arrangement beats a series main with a parallel
  bypass. In that one, RLY_MAIN closing without RLY_BYP following leaves R
  at 85 W indefinitely, and the best you can do is make it unlikely with a
  timer. Here the dangerous state cannot persist by construction.

  Same principle as TS1 backing up fan 1 and as "switches open = 2 V": the
  failure direction is structural, not a promise.

  RLY_MAIN may be the Pico's. Its failure is benign now - the box just does
  not come on.

3a. CONTACT DUTIES - NEITHER RELAY SWITCHES A COLD TOROID
---------------------------------------------------------

  RLY_SOFT  closes into inrush limited by R: 17 A peak.
            Carries 2.92 A for 300 ms only -> a SMALL relay will do.
  RLY_MAIN  closes into an ALREADY ENERGISED transformer, so it sees no
            inrush at all, then carries 2.92 A continuously.

  That is the second advantage of this topology. With a series main plus
  parallel bypass, RLY_MAIN takes the limited inrush AND the continuous
  current, so it has to be the bigger part.

3b. THE COILS ARE NOT OPTICALLY ISOLATED, AND MUST NOT NEED TO BE
-----------------------------------------------------------------

  ** THE RELAY IS THE BARRIER. That is what a relay is. **

  Coil on the Pico's 5 V, contacts on 120 VAC, separated inside the part by
  ~4 kV. An optocoupler in front of the coil would isolate the Pico from its
  own 5 V rail and nothing else.

  And the Pico side is ALREADY mains-isolated by the 5 V module's own
  transformer. Two independent barriers in series:

     mains --[5 V module transformer]-- Pico gnd --[FET]-- coil
     mains --[relay contacts | coil]------------------------+

  The optocouplers elsewhere in this design exist because the two CHANNELS
  float at up to 60 V from each other and have to stack in series. There is
  no relay there to do the job. Here there is.

  What to check instead:
    - coil-to-contact rating: a proper mains relay, 4 kV class. Not a signal
      relay that merely prints 250 V on the contacts.
    - the PCB. Mains relays put coil and contact pins at opposite ends of the
      package for creepage. Do not undo that with a trace.
    - flyback diode across every coil.

3c. DO NOT SUBSTITUTE A ZERO-CROSS SSR
--------------------------------------

  An SSR is optically coupled inside, so it looks like the obvious "already
  isolated" answer. It is the wrong part here, and the main reason is not
  the one people expect.

  ** ZERO-CROSS SWITCHING IS EXACTLY WRONG FOR A TRANSFORMER. **

  Flux is the integral of voltage. Closing at the voltage ZERO CROSSING
  integrates a full half cycle and drives the core to twice its normal peak
  flux - saturation, and the worst inrush available. Closing at the voltage
  PEAK is the gentle case.

  Zero-cross SSRs are built for resistive loads. On a toroid they turn the
  one thing this whole section exists to limit into its worst case.

  Two lesser reasons:
    - a triac SSR drops ~1 V, so 3 W per relay continuously, in a box
      already shedding 108 W. A mechanical contact drops nothing.
    - SSRs fail SHORT. A mechanical relay fails open.

  And note the soft start makes the phase question moot anyway: with R in
  circuit the peak is 17 A whenever in the cycle RLY_SOFT happens to close.
  That is the third quiet virtue of the two-stage arrangement - it removes
  the switching-angle sensitivity entirely, so a plain random-closing
  mechanical relay is all it needs.

4. STAGGER THE TWO TRANSFORMERS
-------------------------------

  Firing both RLY_SOFTs together makes the inrush peaks add - up to 34 A.
  Stagger the two sequences ~200 ms apart and it stays at 17 A, with the
  second starting into a mains already loaded. The Pico is triggering them
  anyway, so this costs one line of firmware.

5. COILS
--------

  4 relays, 5 V coils, ~80 mA each:

      Pico                         100 mA
      3 fans                       600 mA
      opto LEDs                     50 mA
      2 x RLY_MAIN                 160 mA   continuous while running
      2 x RLY_SOFT                 160 mA   300 ms only, never both
      TOTAL                       1070 mA   against the module's 3 A = 2.8x

  Contacts: 10 A / 250 VAC is ample for RLY_MAIN. RLY_SOFT can be smaller -
  it carries 2.92 A for 300 ms and never switches a cold toroid.

  Drive: the 2N7002 boards WITH THE AO3400 SWAP. 80 mA is most of a 2N7002's
  115 mA rating before you count the turn-off spike.
  ** Flyback diode across every coil. ** A relay coil is far more inductive
  than a fan, and the board does not carry one.

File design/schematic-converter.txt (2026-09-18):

BENCH SUPPLY - CONVERTER BOARD, ONE PER CHANNEL
LT8705 SYNCHRONOUS 4-SWITCH BUCK-BOOST, 2-60 V / 3 A to 150 W, 200 kHz
Two of these, identical, isolated from each other. See docs/power-chain.md
Fed from schematic-rectifier.txt - one rectifier board per converter board.
===============================================================================

  28 VAC in from its OWN toroid  ->  ~29-44 V rail  ->  2-60 V out, floating
  Isolated from the other channel by the transformers, so the two outputs
  stack for +/-60 V or 120 V in series. NOTHING on this board may share a
  ground with the control side except through the optocouplers.

  PIN NAMES below are functional. CHECK THEM AND THE PIN NUMBERS against the
  LT8705 datasheet before drawing - this document is the design intent, not a
  transcription.

1. INPUT - FROM THE RECTIFIER BOARD
-----------------------------------

  +RAIL (29-44 V) and RTN arrive from schematic-rectifier.txt, through that
  board's 10 A fast fuse. Heavy pair, but its inductance does not matter:
  this is a 6 A dc feed with 120 Hz ripple, not a switching loop.

  ** Cin IS WHAT MAKES THAT TRUE, AND IT LIVES HERE. **

      +RAIL o---+-------+-------+-------+----> to QA drain, SHORT
                |       |       |       |
               10u     10u     10u     10u     4 x 10 uF / 100 V X7R
               ===     ===     ===     ===     right at the FETs
                |       |       |       |
      RTN   o---+-------+-------+-------+----> to QB source, SHORT

  Cin takes all the di/dt. Worst case is BUCK mode, where the input current
  is pulsed rather than continuous:

      Vout  2 V, D 0.068 -> 0.76 A rms in Cin,  26 mV ripple
      Vout 12 V, D 0.410 -> 1.48 A rms in Cin, 154 mV ripple
      Vout 24 V, D 0.819 -> 1.15 A rms in Cin, 307 mV ripple

  In boost mode the input current is the inductor current and is continuous,
  so Cin barely notices. ~40 uF of 100 V ceramic covers both.

2. POWER STAGE
--------------

         +RAIL                                                    VOUT
           o                                                       o
           |                                                       |
          ===  Cin                                                ===  Cout
          10u x4                                                  bulk polymer
          100 V                                                   100 V + 22u
           |          QA            L1            QD                |  ceramics
           +----------+-+---+-------UUUUU-------+-+---+-------------+
           |          | D |         41.5 uH     | D |               |
           |        G-+-+-+  SW1          SW2   +-+-+-G             |
           |            S |                       | S               |
           |              |                       |                 |
           |          QB  |                   QC  |                 |
           |          +-+-+                   +-+-+                 |
           |          | D |                   | D |                 |
           |        G-+-+-+                   +-+-+-G               |
           |            S |                     | S                 |
           +--------------+---------------------+-------------------+
           |                                                        |
        Rsen_IN                                                  Rsen_OUT
        5 mOhm                                                   15 mOhm
        2512, 1 W                                                2512, 1/2 W
           |                                                        |
           o RTN                                                    o RTN

  QA..QD : 100 V, 20-30 mOhm, Qg <= 50 nC.  ONE part number, four positions,
           but NOT the same duty - see docs/power-chain.md#the-four-switches.
           QA carries the full 6.02 A continuously in boost and does no
           switching; QC and QD take all the switching loss.
           All four TABS ARE AT DIFFERENT POTENTIALS: individual insulators
           on the shared heatsink.

  L1     : Magnetics 0077083A7, Kool Mu 0254, 60u, hand wound.
           24 turns of 3 x AWG18 twisted. Wind 25 and measure - AL is +/-8%,
           which is two turns of spread on its own.
           Wound coil ~OD 43, HT 19 mm. Custom footprint: two pads plus a
           keepout. Do NOT pot it until it measures right.

  Rsen_IN  5 mOhm -> 50 mV at 7.4 A.  This is the INPUT CURRENT LIMIT and it
           is what stops the transformer being overdrawn. It makes the 150 W
           envelope a hardware property rather than a firmware promise.
  Rsen_OUT 15 mOhm -> 50 mV at 3 A.  The user-set CC limit.
           KELVIN both: sense traces from the pad ends, not from the power path.

3. LT8705
---------

                          +--------------------------+
        +RAIL ---Rin---+--| VIN                      |
                       |  |                          |
                     Cvin |                    TG1   |--> QA gate, via 2R2
                       |  |                    BG1   |--> QB gate, via 2R2
                      RTN |                    SW1   |--- QA source / QB drain
                          |                  BOOST1  |--- 100n to SW1, D to GATEVCC
                          |                          |
                          |                    TG2   |--> QD gate, via 2R2
                          |                    BG2   |--> QC gate, via 2R2
                          |                    SW2   |--- QD source / QC drain
                          |                  BOOST2  |--- 100n to SW2, D to GATEVCC
                          |                          |
     Rsen_IN  +-----------| CSP                      |
              +-----------| CSN            INTVCC    |--- 4u7 to RTN
                          |                GATEVCC   |--- 4u7 to RTN
    Rsen_OUT  +-----------| CSPOUT                   |
              +-----------| CSNOUT          EXTVCC   |<-- from local 12 V bias
                          |                          |    (see section 6 - four
        setpoint -------->| FBOUT                    |     FETs at 200 kHz is a
        divider           |                          |     real load on INTVCC)
                          |                          |
        CC threshold ---->| IMON_OUT / ISET          |
                          |                          |
                          |    RT   SS   VC   SYNC   |
                          +----+----+----+-----+-----+
                               |    |    |     |
                            200kHz 100n  comp  GND (or CLKOUT chain)
                             prog        R+C

  EXTVCC matters here: Qg x 4 x 200 kHz is 24-40 mA out of the internal
  regulator at 30-50 nC, and more if a fatter FET is substituted. Feeding
  EXTVCC externally takes the regulator out of the argument.

  The four SRVO_* pins indicate which loop is active - bring them out to the
  ADC so the Pico can display CV / CC / input-limited.

4. SETPOINT: THE SWITCHED CONDUCTANCE DIVIDER
---------------------------------------------

  Vout = Vref * (1 + Rtop * G),  Vref = 1.207 V (FBOUT),  Rtop = 48.7k
  Vout is LINEAR in bottom-leg conductance, so binary-weighted parallel
  resistors give UNIFORM voltage steps. 10 bits = 57 mV over 2-60 V.

      VOUT o---[ Rtop 48.7k 0.1% ]---+---o FBOUT
                                     |
                      +--------------+----------+---- ... ----+
                      |              |          |             |
                   Rfix 74.1k      R9 2.02k   R8 4.05k   ... R0 1037k
                   (no switch)       |          |             |
                                    SW9        SW8           SW0
                                     |          |             |
                                     +----------+---- ... ----+---o RTN

    bit  conductance    resistor        bit  conductance   resistor
     9    493.84 uS      2.02 k          4     15.43 uS     64.80 k
     8    246.92 uS      4.05 k          3      7.72 uS    129.60 k
     7    123.46 uS      8.10 k          2      3.86 uS    259.19 k
     6     61.73 uS     16.20 k          1      1.93 uS    518.39 k
     5     30.87 uS     32.40 k          0      0.96 uS   1036.77 k
    fixed  13.49 uS     74.10 k  -> 2.0 V with every switch OPEN

  ** THE FIXED BRANCH SETS THE MINIMUM AND THE SWITCHES ONLY ADD. **
  Switches open - unpowered, in reset, mid-reflash - is 2 V out, not 60.
  Wire it the other way round and every one of those states commands full
  output. This is structural and must not be "simplified" later.

  SW0..SW9 : two ADG714-class octal SPST in series on one SPI chain.
             ~2.5 Ohm on-resistance: 0.25% error at 60 V, where Rbot is 1k.
             A CD4051 at ~100 Ohm would cost 10% there.
             VERIFY the power-up state is all-switches-OPEN.
  Tolerance: 1% throughout, 0.1% on Rtop and bits 7-9. The 1 M LSB's
             tolerance is worth less than one step.

5. ISOLATED CONTROL - EVERYTHING CROSSES OPTICALLY
--------------------------------------------------

  Pico side                 | barrier |            THIS BOARD's ground
  ------------------------- | ------- | ----------------------------------
  SCK   --[330R]--|>|-------|    |    |-------[10k pull-up]--> ADG714 SCLK
  MOSI  --[330R]--|>|-------|    |    |-------[10k pull-up]--> ADG714 SDI
  CS_SW --[330R]--|>|-------|    |    |-------[10k pull-up]--> ADG714 SYNC
  CS_AD --[330R]--|>|-------|    |    |-------[10k pull-up]--> ADC CS
  MISO  <---[10k]---|<|-----|    |    |<--[330R]-- ADC DOUT / ADG714 SDO
  ------------------------- | ------- | ----------------------------------

  FIVE optos. Four out with their LEDs on the Pico side, ONE back with its
  LED on THIS side. Nothing electrical bridges the gap - these two channels
  get stacked in series, so a shared ground would defeat the transformers.

  SPI, not I2C: every opto is unidirectional and I2C's SDA is not.
  Clock at a few kHz. A 10k pull-up and a phototransistor make edges tens of
  microseconds long; 10 bits then takes single-digit milliseconds, which is
  invisible to someone turning a knob.

  Switch-state readback is free: the ADG714 chain's SDO returns the PREVIOUS
  word on the MISO opto already there for the ADC. Compare it with what was
  sent. On a board that can put 60 V out, a stuck bit is a silently wrong
  output voltage.

  ADC : 12-bit SPI, 4 channels -> Vout divider, Iout (from INA on Rsen_OUT),
        Iin (INA on Rsen_IN), and the SRVO_* loop-status pins.
  INA : high-side, >=80 V common mode (INA293-class). 20 mOhm x gain 50 gives
        3.0 V full scale. A 26 V part will NOT do - the output is the common
        mode and it goes to 60.

6. LOCAL BIAS - AND WHAT IT MUST NOT BE
---------------------------------------

  +RAIL (29-44 V) --> small 60 V buck --> 12 V --> EXTVCC
                                            |
                                            +---> 5 V LDO --> ADG714, ADC,
                                                              INA, opto
                                                              pull-ups

  ** NOT from the control board's 5 V module. ** Feeding this side from the
  control rail wires the two channels together and undoes the isolation the
  second transformer was bought for. Each channel powers its own logic from
  its own rail, which is isolated by construction.

7. OUTPUT
---------

        VOUT o----+--------------------------o + TERMINAL
                  |
                 D_rev   across the output, cathode to +, anode to -
                  |      REVERSE-BIASED in normal use, carries nothing.
        RTN  o----+--------------------------o - TERMINAL
                         Only conducts if the other channel drives this one
                         backwards while it is off, current-limited or
                         shorted. Rate it for the full output current.

  NOTHING IN SERIES WITH THE OUTPUT. A 0.5 V drop is a quarter of the 2 V
  floor, and 1.5 W of heat the load never sees. The same argument is why the
  converter is synchronous.

8. WHAT IS DELIBERATELY NOT ON THIS BOARD
-----------------------------------------

  * No microcontroller. The isolated side holds no firmware - only switches,
    an ADC and a sense amp, doing what they are told. "Switches open = 2 V"
    is then structural and cannot be undone by a hung program.
  * No mains. The transformer primary, its fuse and the inlet live on the
    back wall behind their own shield.
  * No CC error amplifier. The LT8705 carries that loop itself.
  * No fan drive, no display, no 1-Wire. Control board.

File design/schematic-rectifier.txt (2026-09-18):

BENCH SUPPLY - RECTIFIER AND BULK, ONE PER CHANNEL
28 VAC from one ST-1228-T350Q  ->  29-44 V DC rail
===============================================================================

  Separate from the converter board, for three reasons:
    - the bridge dissipates ~12 W and needs a real heatsink
    - four 4700 uF cans are 120 mm of board length and 45 mm tall
    - none of that belongs beside the converter's feedback node

  And it is SAFE to separate because the bulk-to-Cin path is NOT the hot loop.
  The switching loop is Cin(ceramic) -> QA/QB, and Cin lives on the converter
  board. These caps only refill Cin, carrying 6 A dc with 120 Hz ripple, where
  the interconnect's inductance does not matter.

  ** The condition is that the converter board carries ~40 uF of 100 V
     ceramic at the FETs. That is what makes the split safe. **

SCHEMATIC
---------

   toroid secondary          F1            BR1                  F2
   28 VAC, gray 14AWG     20 A blade   35 A bridge          15 A blade
                           58 V type                          58 V type
        o------------------/ /---------~   +------+-------------/ /------o +RAIL
                                                  |                      (29-44 V)
                                       BR1        |
        o---------------------------------~   -   |
                                              |   |
                                              |   +--+--------+--------+--------+
                                              |      |        |        |        |
                                              |     C1       C2       C3       C4
                                              |    4700u    4700u    4700u    4700u
                                              |     63 V     63 V     63 V     63 V
                                              |      |        |        |        |
                                              |     ===      ===      ===      ===
                                              |      |        |        |        |
                                              |      +--------+--------+--------+
                                              |      |                          |
                                              |     R1  bleeder 4k7 / 1 W       |
                                              |      |                          |
                                              +------+--------------------------+----o RTN

PART NOTES
----------

  F1   20 A BLADE, 58 V TYPE. On the SECONDARY - the fuse most often left
       out. A shorted bridge draws the transformer's full 12.5 A
       indefinitely; its thermal fuse will eventually act, but that is a
       one-shot part potted inside the toroid, so you replace the
       transformer, not the fuse.
       The winding carries ~10.1 A rms at full load. 20 A of blade derated
       to the automotive 75% is 15 A continuous - 1.48x, comfortable.

       ** 58 V TYPE, NOT STANDARD 32 V. ** See F2.

  BR1  GBPC/KBPC-style 35 A bolt-down, NOT a DIP bridge. Two diodes conduct
       in series at all times, so P = 2 * Vf * Idc = ~12 W at 6 A. It needs
       the same class of heatsink as the FETs. A low-Vf part saves ~3.5 W.
       Reverse: the rail peaks at 44.3 V, so 200 V is generous and cheap.

  C1-C4  4700 uF / 63 V, 105 C, low-ESR, snap-in.
       ** PARALLELED FOR RIPPLE CURRENT, NOT FOR CAPACITANCE. **
       4 V p-p at 6 A dc needs ~8800 uF, which two cans would cover. But a
       cap-input filter puts 9-12 A RMS through them and a single 10,000 uF
       snap-in is rated 3-4 A. Four is a current decision.
       63 V: the rail peaks at 44.3 V unloaded at high line.

  R1   Bleeder. 18,800 uF at 40 V holds 15 J, which stays there after the
       power is off and the converter board is unplugged. 4k7 / 1 W bleeds
       to nothing in a few minutes and wastes 0.34 W. 40 V is not a shock
       hazard; 15 J into a dropped tool is still a welding event.

  F2   15 A BLADE, 58 V TYPE. 6.02 A carried, 11.2 A at 75% - 1.87x.
       It cannot save a shorted FET: 15 J through 5 mOhm of ESR is 8000 A
       and the FET is gone in microseconds. What it stops is the bulk bank
       emptying into the wreckage afterwards. Speed class is irrelevant at
       8000 A - any blade fuse opens instantly there.

       ** BOTH BLADE FUSES MUST BE THE 58 V TYPE. **
       Standard ATO/ATC are 32 VDC parts, and this rail reaches 44.3 V
       unloaded at high line. Above the rated voltage the arc does not
       self-extinguish: the fuse does not clear, it just keeps burning.
       Same body, same holder, different number printed on it.

       Mains fuses cannot be blade at all - 120 VAC needs a 250 V cartridge.
       Only the low-voltage side goes blade.

WHAT IS NOT HERE
----------------

  * Soft start / inrush limiting. That belongs on the mains PRIMARY, with the
    transformer - a 350 VA toroid's inrush is a primary-side problem. Still
    open: NTC, or a resistor bypassed by a relay.
  * The primary fuse (4 A T) - back wall, with the inlet and its shield.
  * Any reference to the other channel. These two boards share nothing.

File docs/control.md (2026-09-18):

# Control and cooling

What the Pico does, what it deliberately does not do, and how it reaches two
isolated channels without giving the isolation away.

Numbers here come from [`calc/control.py`](calc/control.py).

```bash
python3 docs/calc/control.py
```

---

## The split: hardware closes the loop, the Pico moves the setpoint

**A dedicated TI/Maxim switching controller regulates each channel.** The Pico
never modulates anything. It selects the feedback divider, reads back V and I,
drives the display and the knob, and stages the fans.

This is not a stylistic preference — the RP2040 cannot do the other job:

```
200 kHz -> 5.0 us period
  PWM at 125 MHz: 625 counts = 9.3 bits of duty resolution
  ADC 500 kSPS  -> 2.5 samples per switching cycle
  cycle-by-cycle current limit must act in ~100 ns = 2% of one cycle
  RP2040 has no analog comparator
```

The duty resolution is survivable and the loop bandwidth is arguable. **The
protection is not.** A 180 W converter needs cycle-by-cycle overcurrent limiting
that acts inside a fraction of one switching cycle, and only analog hardware
does that. Lose regulation on a software modulator and 60 V goes into whatever
is plugged in with 8 A of inductor behind it.

The controller handles microseconds. The Pico handles milliseconds and up.

**Check the controller's output rating.** 60 V out means the part must stand
60 V on the output side, and much of the 4-switch buck-boost family stops below
that. Same trap as [the DC-DC module rated 40 V on a 45 V
rail](power-chain.md#the-inductor) — verify before committing.

## Setting the output: switch the bottom leg of the divider

```
Vout = Vref * (1 + Rtop * G)        G = bottom-leg conductance
```

With the **LT8705**'s `FBOUT` reference of **1.207 V** and Rtop 48.7k, Rbot runs
1.00k at 60 V to 74.1k at 2 V — 1000 µS down to 13.5 µS. (See
[the controller](power-chain.md#the-controller-lt8705); this was computed at an
assumed 0.8 V while the part was unchosen.)

**Vout is linear in conductance**, and parallel conductances add, so
binary-weighted switched resistors give *uniform voltage steps*. No lookup
table, no calibration curve:

| bits | step | branches |
|--:|--:|--:|
| 8 | 0.227 V | 8 |
| **10** | **0.057 V** | 10 |
| 12 | 0.014 V | 12 |

**Switch the bottom leg only.** The top leg sits at Vout, and no analog switch
wants 60 V across it.

**Ron hurts most at the top of the range**, because that is where the branch
resistance is smallest:

```
  Ron   5 ohm ->  0.50% at 60 V,  0.01% at 2 V
  Ron  50 ohm ->  5.00% at 60 V,  0.10% at 2 V
  Ron 100 ohm -> 10.00% at 60 V,  0.20% at 2 V
```

A CD4051-class mux at ~100 Ω costs 10 % at full output. Use low-Ron switches, or
fold a known Ron into the branch values.

Keep the divider and its switches **physically at the controller**. The FB node
is the most noise-sensitive point in the converter; running it across the box to
a mux invites instability.

## Not a digipot or a DAC, and the reason is not cost

The obvious simplification is a serial digital potentiometer as the bottom leg.
It fails on resolution. `Rbot` is linear in tap, but `Vout` goes as `1/Rbot`:

```
      near      Rbot     Vout  next tap      step
    60.0V    1.00k   60.00V    50.30V    9.705V
    12.6V    5.00k   12.64V    12.19V    0.447V
     2.0V   49.33k    2.00V     2.00V    0.005V
```

A 50k/256-tap part gives **5 mV steps at the bottom and 9.7 V steps at the top**
— a 2000:1 spread, and unusable where you most want resolution. The
binary-weighted array gives 0.227 V *everywhere* at the same 8 bits, because
conductances add and Vout is linear in conductance.

A DAC injecting into the FB node fixes the linearity but loses the fail-safe:
its zero/reset output is one *end* of the range, and the polarity that would
make 0 V mean 2 V out is the one you cannot have — current sourced into FB
always *lowers* Vout. Getting a safe default back needs an inverting stage or a
watchdog on top of it.

The switched array gets uniform steps and a safe default from the same
property, for the price of some resistors.

## Wire it so a dead Pico gives 2 V, not 60

**Switches open must mean minimum output.** Size the *fixed* branch for 2 V and
let the switches **add** conductance to climb. Then a Pico that is unpowered, in
reset, or mid-reflash leaves 2 V on the terminals.

Wire it the other way round — switches closed for minimum — and every one of
those states commands full output.

## The barrier: optocouplers, but serialised

The two channels are isolated so they can be stacked for ±60 V. **One Pico
touching both feedback networks ties their grounds together and throws that
away.** The Pico stays on its own ground and everything crosses a barrier.

Optos suit this well: the setpoint lines are *static*, changing only when a
human turns a knob, so their speed penalty costs nothing.

**But do not use one opto per bit.**

```
10 bits x 2 channels = 20 switch lines
  one opto per line  -> 20 optos + 20 resistors + 20 pull-ups = 60 parts
  serialised         -> CLK + DATA + LATCH, +1 back for readback
                     -> 8 optos, about 24 parts - a 2.5x saving
```

A **serial-to-parallel device on the isolated side** (powered from that
channel's own rail) takes the clocked stream and drives the switch array. Only
three lines cross per channel:

```
  Pico --SPI--> [opto] [opto] [opto] --> serial-to-parallel --> switch array
                 CLK   DATA   LATCH          (isolated side)        |
                                                                 divider
                                                              bottom leg
```

### Use serial switches, not a shift register plus discrete switches

An **ADG714-class octal SPST** is SPI-controlled analog switches in one package
— it *is* the serial-to-parallel converter and the switch array, and its Ron is
about 2.5 Ω instead of a CD4051's ~100:

```
  Ron   2.5 ohm ->  0.25% error at 60 V (where Rbot is 1k)
  Ron 100.0 ohm -> 10.00% error at 60 V
```

Two daisy-chained give 16 bits of divider off the same three wires. Against
`74HC595` + discrete switches it is fewer parts, far lower Ron and the same
barrier cost. **Verify the power-up state is all-switches-open** — that is the
fail-safe direction, and it is the one thing worth reading the datasheet for
rather than assuming.

Sizing, for a garden-variety transistor-output opto:

```
  If  5 mA -> LED resistor 420 ohm     (RP2040 GPIO sources 12 mA max)
  If 10 mA -> LED resistor 210 ohm
    CTR  80% at If 5 mA -> Ic 4.0 mA;  10k pull-up needs 0.5 mA -> 8x margin
    CTR  40% (aged)     -> Ic 2.0 mA;  10k pull-up needs 0.5 mA -> 4x margin
```

Comfortable even after CTR halves with age. **Run the shift clock at a few kHz,
not at SPI speeds** — a 10k pull-up and a phototransistor make edges tens of
microseconds long. Ten bits then takes single-digit milliseconds, which nobody
turning a knob will notice.

**Power-on state:** the switches must come up open, which is 2 V out. With an
`ADG714`-class part that should be its reset state — confirm it. With a
`74HC595` it is an RC reset on the clear pin. Either way, if the isolated side
browns out the outputs drop and the channel output *falls*. Both safe
directions.

### The interface is SPI, and that is forced by the optos

Every optocoupler is **unidirectional**. I²C's bidirectional `SDA` needs two of
them plus care to avoid latching itself low. SPI's lines each go one way by
definition, so they map onto optos with nothing clever required.

```
  out:  SCK, MOSI, CS_switches, CS_adc   = 4 optos   LED on the Pico side
  back: MISO                             = 1 opto    LED on the ISOLATED side
        5 per channel, 10 total   (against 20+ for one-opto-per-bit)
```

**Every line crosses optically, both directions.** The four outbound ones have
their LEDs on the Pico's side; the return has its LED on the *isolated* side,
driven by the ADC's and switch chip's `MISO` output through its own resistor,
with the phototransistor on the Pico. Nothing electrical bridges the gap — which
is the whole point, since these two channels get stacked in series.

That return opto is subject to the same speed limit as the rest: tens of
microseconds with a 10k pull-up. It bounds `MISO` exactly as it bounds `SCK`, so
the few-kHz clock covers both.

### Readback crosses the same barrier — and switch state comes free

The Pico needs current, voltage, and **confirmation that the switch word it
sent is the one that actually latched**. All three come back on that single
`MISO` opto.

**Switch state costs nothing extra.** The daisy-chain output of the switch chip
(or a `74HC595`'s `QH'`) shifts out what was previously loaded. Clock the new
word in and the old one comes back on the `MISO` line already there for the ADC.
Compare it against what was sent last time, and a bit corrupted in the barrier
becomes visible. On a box that can put 60 V out, that is worth having — an
undetected stuck bit is a wrong output voltage, silently.

**Current sense:**

```
   shunt   V at 3A        P   gain for 3.3V   12-bit LSB
     10m    30.0mV     90mW            110       0.73mA
     20m    60.0mV    180mW             55       0.73mA
     50m   150.0mV    450mW             22       0.73mA
```

**20 mΩ with a gain-50 amp** gives 3.0 V full scale — a stock INA gain, 180 mW
in the shunt, 0.73 mA per count at 12 bits.

High-side sensing puts the output on the amplifier's **common mode: up to 60 V**.
That needs an `INA293`-class part rated ≥80 V CM, not a garden-variety 26 V one.
Low-side is easier but puts the shunt in the return, which regulation then has
to account for.

### Current limit is analog too — and the LT8705 already has it

The Pico reads current; it must not *enforce* the limit. Constant-current mode
needs an analog loop, and the [LT8705](power-chain.md#the-controller-lt8705)
carries one of its own — one of its four servo loops regulates output current.
**The Pico sets the CC threshold; the chip enforces it.**

An external error amplifier diode-OR'd into the feedback node was the plan while
the controller was unchosen. It is no longer needed.

This is the same argument as the main loop, and it matters more here: a short
circuit on the output is exactly the case where a millisecond-scale software
response is too slow.

## Decided: the isolated side stays dumb

Per-channel microcontrollers were considered — a small MCU on each switcher
board, talking to the Pico over a serial link — and rejected. **The isolated
side holds no firmware.** Only switches, an ADC and a sense amp, doing what they
are told over SPI.

### "Offload the work" is not an argument, because there is no work

```
BUS OCCUPANCY - how busy the wires are:
  V/I readback, 32 bits, 10 Hz, x2 channels     12.8%
  1-Wire read, 3 sensors, 1 Hz                   1.5%
  setpoint, only on knob turns                   0.1%
  TOTAL                                         14.4%

CPU OCCUPANCY - SPI on DMA, 1-Wire on PIO
  well under 1% of ONE of two cores at 125 MHz
```

The DS18B20's 750 ms conversion is **latency, not occupancy** — issue the
convert, go away, come back. Blocking on it would be a firmware bug, not a
reason to add silicon.

### What would genuinely argue for it, if this is ever revisited

- **2 optos per channel instead of 5** — 4 total rather than 10
- **Calibration lives on the channel**, so a board carries its own constants
- **Local housekeeping shares the channel's ground**, which would make the
  sensor-isolation problem vanish rather than be designed around

### Why not, anyway

It is roughly a wash on parts — six optos saved against two MCUs, their
supplies and decoupling — and plainly not a wash on firmware: two more
codebases, two more bootloaders, and version skew between them and the Pico. It
also does not touch the hard part, since [CC and cycle-by-cycle
protection](#current-limit-is-analog-too--and-the-lt8705-already-has-it) stay analog either way.

**And it would weaken the fail-safe.** "Switches open = 2 V" is currently
*structural*: it holds when the isolated side is unpowered, resetting, or being
reflashed, because it is a property of the resistor network rather than of any
code. A hung MCU holding a high setpoint is a state that cannot exist today, and
adding one would create it.

A side that can only do what it is told, with its safe default built into the
divider, is far easier to reason about than one running its own program.

### RS-232 would have broken the isolation outright

Worth recording as a trap rather than a preference. **RS-232 is
ground-referenced** — ±12 V signalling against a common return — so wiring it
between the Pico and a channel board ties those grounds together and destroys
the barrier. That is the same failure as [powering the isolated side from the
control rail](#what-the-module-must-not-power-the-isolated-sides) or bolting a
sensor to a heatsink: the fourth way to give it away by accident.

Isolated RS-232/RS-485 transceivers exist, but they are digital isolators with a
transceiver bolted on — you pay for the isolation either way, so pay for it with
optos.

If MCUs ever do go in, the link is **optical UART at 9600**. 19200 is already
marginal through a cheap opto at 52 µs per bit, and nothing here needs the
speed:

```
    2400 baud ->  416.7 us per bit   fine
    9600 baud ->  104.2 us per bit   fine
   19200 baud ->   52.1 us per bit   marginal
  115200 baud ->    8.7 us per bit   needs a fast opto
```

## Cooling

```
  100 W:  10 K rise -> 17.6 CFM   15 K -> 11.7 CFM   20 K -> 8.8 CFM
   60 W:  10 K rise -> 10.5 CFM   15 K ->  7.0 CFM   20 K -> 5.3 CFM
```

Three 40 mm fans give 9–15 CFM installed, which lands on 100 W at a 15 K rise.
One 80 mm would move the same air far more quietly — **staging is what buys the
quiet at low load**, which is most of the time.

### Temperature sensing: 1-Wire, and isolated by the packaging

**The deciding question is not which bus. It is where the sensors sit
electrically.**

The temperature that matters is the pass-element heatsink. In a 4-switch
buck-boost the FET tabs are switching nodes, so they mount on insulators and the
heatsink is then tied to **its own channel's ground** for EMI. Channel A's
heatsink and channel B's are therefore at two different potentials — and when
the channels are stacked for ±60 V, 60 V apart.

**A metal-cased sensor bolted to each, both wired back to the Pico's ground,
bridges the two channels and undoes the isolation.** Again — this is the third
place the barrier can be given away by accident, after the setpoint divider and
the control rail.

Couple them thermally and isolate them electrically, and the problem disappears:
every sensor then lives on the Pico's ground, nothing crosses the barrier, and
the bus choice becomes free.

| | 1-Wire (DS18B20) | I²C (TMP102/LM75) |
|---|---|---|
| pins | **1** + pull-up | 2 |
| sensors per bus | many, unique 64-bit IDs | 8 addresses typical |
| cable runs | designed for metres | keep short — bus capacitance |
| addressing | automatic | plan addresses, strap pins |
| conversion | 750 ms at 12-bit | tens of ms |
| isolated probe form | **stainless, off the shelf** | rare |

**1-Wire.** One GPIO for the lot, sensors spread over a 285 mm box, no address
planning — and the stainless probe form is **electrically isolated by
construction**, which solves the problem above through packaging rather than
through care. (Good enough for a 60 V heatsink. It is not safety insulation, so
do not use one against anything at mains potential.)

The 750 ms conversion looks slow and is not. A heatsink's thermal time constant
is tens of seconds, so sampling at 1 Hz gives ~60 samples per time constant —
two orders of magnitude more than the control needs. **Thermal management is not
a fast loop.**

Neither bus would survive the opto barrier, incidentally: both are
bidirectional, and `SDA` and the 1-Wire data line have the same problem
[`MISO` does not](#the-interface-is-spi-and-that-is-forced-by-the-optos). Another
reason to keep the sensors on the Pico's side.

### Three sensors, and what each is for

| where | for |
|---|---|
| **pass-element heatsink** | drives the fan staging — it leads everything else by a long way |
| **toroid** | slow and high-mass, and it has its own thermal fuse; logging and a shutdown backstop |
| **intake air** | ambient reference. In the fan stream, away from any heatsink, or it reads its own self-heating |

The thresholds below belong to the **heatsink** sensor.

### A failed read must stage up

CRC failure, a missing sensor, a shorted bus: the firmware treats that as **hot**
and runs the fans. Not as cold, and not as "hold the last value". Same principle
as TS1 backing up fan 1 — the failure direction has to be the safe one.

### Stage on thresholds with hysteresis, not on "still rising"

| | on | off |
|---|--:|--:|
| fan 1 | 35 °C | 30 °C |
| fan 2 | 45 °C | 40 °C |
| fan 3 | 55 °C | 48 °C |
| **TS1** | **~65 °C** | **~55 °C** |

A rising-derivative trigger fires on every load step and every lid opening, and
it is hard to tune because dT/dt is noisy at any sane sample rate. Absolute
thresholds with a few degrees of backlash will not chatter.

### Fan 1 is staged like the others — TS1 is what makes that safe

**Cooling must not depend on firmware.** The way to satisfy that is *not* to
hardwire fan 1 permanently on, which would throw away useful control for no
reason. It is a **bimetallic thermostat in parallel with fan 1's drive FET**.

```
   FAN1 o----+-------[ AO3400 ]------- GND    <- Pico, normal staging
             |
             +-------[  TS1   ]------- GND    <- closes at 65 C regardless
```

In normal operation the Pico stages fan 1 like the others and **TS1 never
closes** — it sits above fan 3's threshold on purpose. If the Pico is halted,
hung, or mid-reflash, the heatsink climbs to 65 °C and TS1 runs the fan
directly, with no software in the path at all.

One part, and it keeps both properties instead of trading one for the other.
Mount it on the same heatsink as the 1-Wire probe that drives the staging —
they are watching for the same thing; TS1 just does not need anyone listening.

**It also costs the Pico's last GPIO.** Driving all three fans takes the budget
to 26 of 26.

The expansion route is an **MCP23017 on the display's I²C bus**, which costs
**zero additional pins** — the bus is already there — and is the same part
TritonECU runs at 0x20. Move the slow outputs onto it:

```
  RLY_MAIN x2  2   NE556 triggers x2  2   fan 1/2/3  3   =  7 freed
  GPIO      26 used -> 19 used, 7 spare
  expander  7 of 16 used
```

**Not the encoders.** Quadrature needs prompt reads, and an expander behind a
bus turns a knob into a source of missed counts.

Its failure mode is already covered: a dead expander loses the relays (the box
does not come on — benign) and the fans (TS1 closes at 65 °C regardless). The
thermostat that made fan 1 safe to software-control is the same thing that makes
it safe to put behind an expander.

### The auxiliary supply: one 5 V module off the mains

**5 V fans settle it** — there is no 12 V rail in the box at all. A single
off-the-shelf 120 V → 5 V module runs the Pico, the fans and the opto LEDs.
Neither can come off an adjustable channel, for the same reason as [not putting
the fan on the adjustable
rail](../README.md#the-fan-is-not-a-load-for-the-adjustable-rail): the user can
turn that rail down.

```
  Pico (RP2040, no radio)                      100 mA
  3 x 5 V 40 mm fans @ ~200 mA                 600 mA
  opto LEDs, 10 x 5 mA (worst case all on)      50 mA
  TOTAL                                        750 mA = 3.8 W

  5 W module  -> 1.0 A, 1.3x headroom   MARGINAL
  10 W module -> 2.0 A, 2.7x headroom   comfortable
```

**Buy the 10 W, not the 5.** The fans dominate and they draw their worst at
startup, all three at once if the box comes up hot.

Give the fans their own decoupling, or their own feed from the module. Brushed
or not, fan commutation puts spikes on the rail, and the Pico's ADC is reading
millivolts of shunt signal.

### What the module must NOT power: the isolated sides

Each channel's switch chip, ADC and sense amp sit on **that channel's ground**.
Feeding them from the control 5 V rail wires the two channels together and
undoes the isolation the second transformer was bought for.

They power themselves locally, and it costs nothing: each channel already has
its own ~40 V raw rail from its own toroid, isolated from the other by
construction. Either a small 60 V-capable buck per channel, or — check this
first — **the switching controller's own VCC/bias output**, which on many parts
can spare the tens of milliamps this needs.

### The module

| | |
|---|---|
| Rating | **5 V 3 A, 15 W**, isolated, 100–264 VAC in |
| Board (YS-U20S drawing) | 86.5 × 46.5 mm, ~24 mm tall (2 mm PCB + 22 mm parts) |
| Mounting | 4 × Ø3.2 |
| Terminals | 5.08 mm screw blocks both ends — `ACL`/`ACN` in, `+V`/`−V` out |

**3 A against a 750 mA load is 4× headroom** — comfortably past the "buy the
10 W not the 5 W" line, and enough to fix the airflow shortfall below by going
to 60 mm fans without worrying about the supply.

Screw terminals at both ends are welcome: no soldering to mains, and the DC side
lands straight on the control rail. The universal 100–264 V input also means it
does not care what the mains does.

> **Two datasheets, possibly two parts.** The mechanical drawing is a
> **YS-U20S** at 86.5 × 46.5 × 24; the linked NOYITO listing describes itself as
> *ultra-small*, which 86.5 mm is not. They may be the same board rebadged or
> they may not. **Take the mechanical numbers from whichever one actually
> arrives** — the enclosure depends on them, and the "on edge in the back bay"
> conclusion below is computed from the YS-U20S drawing.

#### Fuse the branch — 1 A, not 3

A separate fuse on this branch is right: the C14's fuse is sized for the whole
box and would never notice a fault in a 156 mA load. The value is the problem.

```
  at its 15 W rating        18.8 W in ->  156.2 mA
  at the real 3.8 W load     5.1 W in ->   42.2 mA
```

**A 3 A fuse is 19× the module's maximum input current.** The module can fail
short and cook without ever blowing it. A fuse that cannot blow is not there.

```
  0.25 A time-delay -> 1.6x rated draw   tight, inrush may nuisance-trip
  0.5  A time-delay -> 3.2x rated draw   sensible
  1.0  A time-delay -> 6.4x rated draw   sensible  <- chosen
  3.0  A               19x rated draw    cannot clear a fault in this branch
```

**1 A time-delay.** Time-delay rather than fast, because the module's input
capacitor charges through the fuse at switch-on. 1 A is the looser end of
sensible — it will clear a hard short but not a partial failure drawing a few
hundred milliamps — and it is stocked everywhere in 5 × 20, which 0.5 A often
is not.

#### All three branches, since the inlet now feeds three loads

| branch | draw | fuse |
|---|--:|---|
| toroid A primary, 350 VA | 2.92 A | 5 A time-delay |
| toroid B primary, 350 VA | 2.92 A | 5 A time-delay |
| 5 V control module | 0.16 A | **1 A time-delay** |
| **total** | **5.99 A** | 10 A time-delay at the C14 |

All three are **5 × 20 mm cartridge, 250 V** — mains cannot use blade fuses.
Values allow for derating: a cartridge fuse runs at ~89 % of its rating at the
45 °C inside this box, so the primary went 4 A → 5 A (a 4 A derates to 3.6
against a 2.92 A load, which blows on a warm day).

The 10 A at the C14 is also the inlet module's own ceiling, so there is no room
above it. It only binds with both channels at full output simultaneously, and
each leg has its own branch fuse — but it is the reason not to grow the load.

The **low-voltage** fuses are blade, and they are in
[`design/schematic-rectifier.txt`](../design/schematic-rectifier.txt): 20 A on
each secondary, 15 A on each DC rail, **58 V type** because the rail reaches
44.3 V and standard blade fuses are 32 V parts.

### The Pico owns one relay per transformer, but not both

Soft start is in [`design/schematic-mains.txt`](../design/schematic-mains.txt),
and it splits along the same fail-safe line as everything else:

Two parallel paths — **soft first, then main** — rather than a series main with
a parallel bypass:

| relay | duty | owner |
|---|---|---|
| `RLY_SOFT` | energises through the 10 Ω resistor, **300 ms one-shot** | 555 monostable |
| `RLY_MAIN` | bypasses the resistor, carries 2.92 A running | **the Pico** |

**The one-shot is the whole safety argument.** `RLY_SOFT` drops out by itself
whether or not anything else worked — so if `RLY_MAIN` never closes, the box is
simply off rather than holding 85 W in a resistor. In a series-main-plus-bypass
arrangement that same failure leaves the resistor cooking indefinitely and the
best you can do is make it unlikely. Here **the dangerous state cannot persist
by construction.**

It also means neither relay ever switches a cold toroid: `RLY_SOFT` sees inrush
already limited to 17 A, and `RLY_MAIN` closes into an energised transformer.

The Pico triggering the sequence lets it **stagger the two transformers ~200 ms
apart**, halving the combined inrush from 34 A to 17 — one line of firmware,
since it is triggering them anyway.

Four more 5 V coils at ~80 mA bring the control rail to **1070 mA against the
module's 3 A**. Flyback diode across every coil: a relay coil is far more
inductive than a fan, and the driver board does not carry one.

The branch values differ by **8:1**, which is exactly why branch fusing earns
its keep — one 8 A fuse upstream protects the cord and nothing else. The inlet
module is rated 10 A; that is a ceiling, not a recommendation.

Toroid primaries want time-delay regardless: a 350 VA toroid's inrush will pop
a fast fuse of any sensible rating, which is the same reason [the soft
start](power-chain.md#what-this-does-to-the-enclosure) is on the list.

#### It is open frame — so it needs a cover too

This is the part that matters. It is a **bare PCB with live AC terminals and a
live primary side** — so the inlet's spades are no longer the only exposed mains
in the box, and the [shield](../README.md#the-inlet-is-on-the-back-wall--and-brought-a-shield)
no longer covers everything that needs covering.

It needs the same treatment: a printed hood over it, or mounting it inside an
extension of the mains shield. The same rule applies either way — **no exposed
mains that a finger can reach with the lid off.**

#### Where it goes: landscape on the back wall, beside the inlet

Mounted **landscape, flat against the back wall**, low, at the **END A end** —
the intake end, so it sits in cool air rather than the exhaust, and close to
where the fans cluster.

**Not above the inlet.** The mains shield's roof is at z 68.5 and the rim taper
starts at 89, so there is **20.5 mm** of height above it and the board needs
46.5 landscape. Beside it there is **118 mm** of clear wall each way for an
86.5 mm board.

Standing it against the wall also solves the depth problem: lying on the floor
the board needs 46.5 mm and the back bay has 34; stood up it projects only its
24 mm of components plus standoffs, and the shell comes to **31.5 mm** — the
same 2.5 mm gap to the supply that the mains shield has.

```
5V shell  95.5 x 31.5 x 51 at x 62 on the back wall
          bay spare 2.5, gap to the mains shield 10.75
```

#### How it is held: two screws through the back wall

**Side tabs to floor posts were the first attempt and do not fit** — shell plus
tabs is 123.5 mm against 115 mm of free wall. Two M3 screws through the back
wall from outside, into blind bosses inside the shell, cost no length at all.
Same idea as the fan, which also screws in from the outside face.

**The bosses are blind on purpose.** The screw must stop in plastic and never
break through into the shell's interior, because that interior is mains.

#### It makes the inlet a distribution point

The IEC inlet now feeds **three** loads: toroid A's primary, toroid B's primary,
and this module's AC input. The shield was sized for three booted spades
*leaving* it. It is now a junction, and either it grows to hold a small mains
terminal block or that block lives beside it under its own cover.

Worth settling before the toroid layout is drawn, because it changes what the
back bay has to contain.

### Driving the fans: the 2N7002 boards, with a bigger transistor

The [2N7002 driver boards](../../TritonECU/hardware/2N7002%20Driver/) are the
right *shape* for this — but they were specified for 14 mA into a DM542
optocoupler, and a fan is fifteen times that.

```
 fan current   vs 115 mA rating     Vds   P in FET     verdict
       80 mA              0.7x   0.40V       32mW      ok
      120 mA              1.0x   0.60V       72mW      OVER RATING
      200 mA              1.7x   1.00V      200mW      OVER RATING
      250 mA              2.2x   1.25V      312mW      OVER RATING
```

A SOT-23 sheds roughly 200–350 mW at 25 °C and far less in a box already
shedding 100 W. Starting current is 2–3× running, so a 200 mA fan asks for
**400–600 mA at switch-on**. And that table is optimistic: it assumes 5 Ω, which
is the 2N7002 well enhanced — a **3.3 V** Pico GPIO does not enhance it that
far, so the real drop and dissipation are worse.

#### Keep the boards, swap the FET

The board carries the parts that actually matter: the 220 Ω gate resistor and,
more importantly, the **10 kΩ gate pulldown** that holds the FET off while the
Pico's GPIOs are high-impedance during boot. Both are right for any N-FET.

```
  2N7002  SOT-23: pin1 Gate, pin2 Source, pin3 Drain
  AO3400A SOT-23: pin1 Gate, pin2 Source, pin3 Drain   -- same pinout
```

| | Rds(on) @ Vgs 4.5 | at 250 mA | rated |
|---|--:|--:|--:|
| 2N7002 | 5 Ω | 1250 mV, 312 mW | 0.12 A |
| **AO3400A** | **28 mΩ** | **7 mV, 1.8 mW** | **5.7 A** |

A true logic-level part with Vgs(th) under ~1.2 V, so a 3.3 V gate fully turns
it on. Same footprint, same pinout, same passives — a transistor swap, not a
redesign.

#### Add a flyback diode, which the board does not have

A fan is an inductive load and the board leaves the drain open with no freewheel
path, so switching off spikes it. The 2N7002's 60 V gave some margin; an
AO3400's 30 V gives less. **A diode across each fan, cathode to +5 V** — a
1N4148 is ample at these currents.

#### Three boards, and three flyback diodes

All three fans are switched and temperature-staged. Fan 1's
firmware-independent backstop is [TS1](#fan-1-is-staged-like-the-others--ts1-is-what-makes-that-safe),
a thermostat in parallel with its FET — not a hardwired supply.

### Check the fans actually move the air

```
  needed: 11.7 CFM for 100 W at a 15 K rise
  12 V 40 mm: ~8 CFM free, ~4.0 installed -> 3 of them = 12.0 CFM   OK
   5 V 40 mm: ~5 CFM free, ~2.5 installed -> 3 of them =  7.5 CFM   SHORT
```

A 5 V fan of a given size spins slower than its 12 V cousin, so **three 5 V
40 mm fans may not reach the number**. Check the CFM on the fans actually in
hand against 11.7. If they are short, the answer is 60 mm rather than a fourth
40 — more area at lower RPM is quieter as well as better.

## Open

- 4-pin PWM fans instead of on/off staging? Continuous ramping is quieter and
  the Pico has PWM to spare.
- Resolution: 10 bits gives 57 mV steps. Fine for a bench supply, coarse for
  anything calibrated.
- Whether a watchdog should clear the switch array if the Pico stops talking.
  The register currently holds its last setpoint, which fails *level* rather
  than *safe* — acceptable, since it cannot fail upward.

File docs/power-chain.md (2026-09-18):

# Power chain

What the bench supply is, and why it is shaped this way. The enclosure follows
this document, not the other way round — and **as of this writing the enclosure
in `bench_supply.scad` is the wrong box for it.** See [What this does to the
enclosure](#what-this-does-to-the-enclosure).

Every number below comes out of the scripts in [`calc/`](calc/). Run them
rather than trusting the tables.

```bash
python3 docs/calc/power_budget.py    # transformer, rails, power, heat
python3 docs/calc/inductor.py        # core geometry, winding, losses
python3 docs/calc/core_choice.py     # which core to buy, solved under DC bias
python3 docs/calc/floor.py           # floor thickness under the transformers
python3 docs/calc/control.py         # setpoint divider, opto barrier, fans
python3 docs/calc/fets.py            # the four switches and their heatsinking
```

Control electronics and cooling are in [`control.md`](control.md).

---

## What it has to be

| | |
|---|---|
| Channels | **2** |
| Range | **2 V to 60 V**, adjustable |
| Current | **3 A**, to a **150 W per channel** ceiling — see the envelope |
| Regulation | both channels regulated |
| Isolation | **channel to channel**, so they can be wired in series for ±60 V |

That last line is the one that shapes everything. Two independent supplies that
can be stacked is a different machine from one supply with two rails.

## The transformer

**Seco-Larm ST-1228-T350Q**, from
[its datasheet](https://www.seco-larm.com/wp-content/uploads/2021/08/PI_ST-1228-T350Q_200728.pdf):

| | |
|---|---|
| Output | **28 VAC**, 12.5 A, 350 VA |
| Secondary | **one winding**. "Output wire Gray, AWG#14" — no centre tap |
| Input | 120 VAC, brown AWG#18 |
| Size, mass | 113 × 117 × 70 mm, **2.90 kg** |
| Built in | thermal fuse, transient suppressor, shielded windings |

The 28 V is not on the nameplate as such — it is 350 VA ÷ 12.5 A, and the model
number reads ST-12/**28**. It is a security-industry transformer meant to feed
Seco-Larm's own ST-2406 AC→DC units, which is why it has one plain winding.

## 350 VA is not 350 W

A capacitor-input filter draws short, tall current pulses. The winding sees an
RMS current much larger than the DC the rectifier delivers, so the usable DC
power is about **62 %** of the VA rating:

```
350 VA x 0.62 = 217 W DC usable
```

This single derating decides the rest of the document. Skip it and every power
budget comes out about 60 % too optimistic.

## One transformer is one channel

```
one channel, 60 V x 2.5 A = 150 W out
  -> 176 W DC in at 85%   -> needs 285 VA     against 217 W available: +41 W
both channels             = 300 W out
  -> needs 569 VA                             one 350 VA is 61% of that
```

**So: one transformer per channel — two ST-1228-T350Q.**

### It is power limited, not current limited

**3 A up to 50 V, tapering to 2.5 A at 60 V**, 150 W per channel. The
transformer does not care about amps, it cares about watts — 3 A at 12 V is 36 W
and nothing to it. A flat 2.5 A derate would have thrown the bottom of the range
away for no reason.

### The envelope, per channel

| V | I max | P | limited by |
|--:|--:|--:|---|
| 2 V | 3.00 A | 6 W | current |
| 5 V | 3.00 A | 15 W | current |
| 10 V | 3.00 A | 30 W | current |
| 12 V | 3.00 A | 36 W | current |
| 15 V | 3.00 A | 45 W | current |
| 20 V | 3.00 A | 60 W | current |
| 24 V | 3.00 A | 72 W | current |
| 30 V | 3.00 A | 90 W | current |
| 36 V | 3.00 A | 108 W | current |
| 40 V | 3.00 A | 120 W | current |
| 45 V | 3.00 A | 135 W | current |
| 48 V | 3.00 A | 144 W | current |
| **50 V** | **3.00 A** | **150 W** | **the corner** |
| 52 V | 2.88 A | 150 W | **power** |
| 55 V | 2.73 A | 150 W | **power** |
| 58 V | 2.59 A | 150 W | **power** |
| 60 V | 2.50 A | 150 W | **power** |

**Both channels can do this at once**, because each has its own transformer.
That is what the second ST-1228 buys, beyond the isolation.

### Stacked and paralleled

The channels are isolated, so they combine — which was the point:

| configuration | range | notes |
|---|---|---|
| **series** | to **120 V**, 3 A below 100 V, 2.5 A at 120 V | 300 W total |
| **± split** | **±60 V** about a common centre | the original requirement |
| **parallel** | to **6 A** below 50 V | 300 W total, but see below |

**Series needs a reverse-protection diode across each output — across, not in
series with it.** If one channel is off, current-limited or shorted while the
other is driving, the live one pushes current backwards through the dead one,
and the diode gives that current somewhere to go.

```
      +out ---+-------------------> load
              |
            [diode]   cathode to +out, anode to -out
              |
      -out ---+------------------->
```

It sits **anti-parallel** with the output and is reverse-biased in normal
operation, so it carries no current and drops nothing. Rate it for the full
output current, because that is what it has to survive when it does conduct.

**Nothing goes in series with the output.** A series diode would be intolerable
at the bottom of the range:

```
   Vout    drop    error  loss at 3 A
    2 V    0.5V    25.0%        1.5 W
    5 V    0.5V    10.0%        1.5 W
   60 V    0.5V     0.8%        1.5 W
```

0.5 V on a 2 V output is a quarter of it. Even inside the sense loop, where the
regulator could compensate, it is 1.5 W of heat and a volt the load never sees.
The same argument is why the converter is [synchronous](#synchronous-and-here-that-is-load-bearing):
no junction drops anywhere in the conduction path.

**Parallel is the awkward one.** Two independently regulated voltage sources
fight: whichever reads fractionally higher takes the whole load until it hits
its current limit. Run one channel in CC at the current you want it to
contribute and let the other regulate the voltage, or do not parallel them.

The inductor is sized by the **worst case, not the current cap**: boost at low
line and full power is 6.02 A, and in buck mode the inductor carries the
*output* current, so 3 A there is well under it. One design covers the whole
envelope.

#### Why 150 W and not the 184 W the transformer can just about give

3 A at the full 60 V is 180 W, and one transformer *just* covers it — 342 VA
needed against 350 available, a 2 % margin. The problem is what that margin
consists of:

```
 converter eff    DC in   VA needed    margin
          90%     200W        323      +27   ok
          85%     212W        342       +8   ok      <- the assumption
          82%     220W        354       -4   OVER
```

**Converter efficiency was the entire margin**, and the cap-input factor
multiplies it — at 0.58 rather than 0.62 it is over at any efficiency. Both are
estimates.

Capping at 150 W buys **+41 VA** and moves efficiency from being the deciding
variable to being a detail. It costs only the top corner — the last half amp
above 50 V — and the transformer's thermal fuse stops being something you
design against.

## Isolation comes from the iron, not from the converters

Rectifying one winding twice does not isolate anything. Both outputs still share
the winding, so they cannot be stacked. The barrier has to exist somewhere, and
there are only two places to put it:

| Where | What it costs |
|---|---|
| **In the converters** — two isolated flybacks | custom-wound transformer each, snubber, optocoupler feedback. The hard path |
| **In the iron** — two mains transformers | one more 2.9 kg toroid, and the converters become ordinary non-isolated buck-boosts |

Since 2.5 A per channel already forces a second transformer for power reasons,
**the isolation is free.** That is the argument for buying the second ST-1228
rather than designing two flybacks: it is not really about the iron, it is about
not having to carry a safety barrier inside a switching converter.

```
toroid A -> bridge -> rail A -> buck-boost -> channel A   (floating)
toroid B -> bridge -> rail B -> buck-boost -> channel B   (floating)
                                   series them for +/-60 V
```

## The converter has to boost, and it is not a SEPIC

**Boost is a requirement.** The raw rail is nowhere near 60 V, and it is at its
lowest exactly when the demand is highest:

```
  132 V, no load    44.3 V   60 V needs 1.35x
  120 V, no load    40.2 V   60 V needs 1.49x
  120 V, loaded     32.7 V   60 V needs 1.84x
  108 V, loaded     29.3 V   60 V needs 2.05x   <- design case
```

Low line and loaded is the worst case, and the converter has to make **2.05×**
there. No buck and no linear regulator steps up at all, so the topology must be
buck-boost across the whole range.

**But not a SEPIC.** The
[3–30 V SEPIC work](../../3-30-sepic-3A-DCtoDC/README.md) is 3 A at 5 V — 15 W.
This is **180 W per channel, twelve times that**. A SEPIC's coupling capacitor
carries the full ripple current, and at this power that is a punishing part to
specify and a hot one to live with. Use a **4-switch buck-boost**, or a boost
stage feeding a buck stage. The topology reasoning from the SEPIC documents
carries over; none of the part selection does.

There is also no *switchover* to design. A buck-boost crosses unity gain
continuously — one converter covers 2 V and 60 V with no handover, no relay and
no second regulator to swap in.

## The controller: LT8705

**Analog Devices LT8705**, synchronous 4-switch buck-boost, one per channel.

| | |
|---|---|
| Input | 2.8 – **80 V** |
| Output | 1.3 – **80 V** |
| Switching | 100 – 400 kHz — our 200 kHz sits mid-range |
| Drivers | quad N-channel, so all four switches are FETs |
| Loops | **four**: input voltage, input current, output voltage, output current |

### Why not the obvious TI part

A 60 V output rules out most of the family, which is the trap flagged earlier
and worth showing rather than asserting:

| part | input | output | verdict |
|---|---|---|---|
| **LM5176** (TI) | 4.2–55 V, 60 abs max | ~55 V | our 60 V is **at or over** the limit |
| **LT3790** | 60 V | 60 V | exactly at the limit, **zero margin** |
| **LT8705** | 2.8–80 V | 1.3–80 V | **20 V of margin on both** |

It is an ADI part rather than the TI/Maxim used elsewhere in these projects.
That is the cost, and it is not much of one.

### Synchronous, and here that is load-bearing

All three candidates are synchronous — but it is worth recording *why* not to
substitute a cheaper asynchronous part later:

```
  boost rectifier, diode : 0.5 V x 6.02 A x 0.488 = 1.47 W
  boost rectifier, FET   : 6.02^2 x 28 mOhm x 0.488 = 0.50 W
  buck low side at 12 V, diode : 0.89 W
  buck low side at 12 V, FET   : 0.15 W
  saved: 1.71 W = 1.1 percentage points at 150 W out
```

**Efficiency is the margin in this design.** The budget fits at 85 % with
+8 VA and is *over* at 82 %. Giving a point and a half away to diode drops
gives away most of what capping at 150 W just bought back.

### The input current loop is the feature that matters most

The transformer gives 217 W DC. At the 29.3 V the rail sags to, that is
**7.4 A** of input current.

Set the LT8705's input current limit near there and **the 150 W envelope stops
being a firmware promise and becomes a hardware property.** The transformer
cannot be overdrawn even if the Pico is wrong, hung, or being reflashed. Nothing
else in this design protects the transformer that directly.

### And the output current loop removes a part

CC mode is built in, so the external error amplifier diode-OR'd into the
feedback node — specified in [`control.md`](control.md#current-limit-is-analog-too--and-the-lt8705-already-has-it)
— is no longer needed. The Pico sets the CC threshold; the chip enforces it.

### It also moves the setpoint divider

`FBOUT` regulates at **1.207 V**, not the 0.8 V assumed while the part was
unchosen:

```
  Rtop/Rbot 0.657 at 2 V to 48.7 at 60 V   = 74:1
  with Rtop 48.7k: Rbot 1.00k at 60 V ... 74.1k at 2 V
  conductance 1000 uS ... 13.5 uS
```

Still **linear in conductance**, so binary-weighted switched resistors still
give uniform steps — 10 bits is 57 mV as before. And the part's 1.3 V minimum
output clears our 2 V floor.

## The four switches

Sized from the operating points, in [`calc/fets.py`](calc/fets.py). Two results
are not obvious, and both push against the instinct to buy the lowest Rds(on)
available.

### Specification

| | |
|---|---|
| Rating | **100 V** — one part number for all four |
| Rds(on) | **20–30 mΩ** |
| Gate charge | **≤ 50 nC** — this is the binding parameter |
| Package | TO-220 on a shared heatsink, or D2PAK with good copper |

Candidates in that window: `STD26NF10` (100 V, 33 mΩ, DPAK, low-Qg STripFET),
`STP40NF10L` (designed for minimised gate charge), or an SGT-trench part such as
MCC's `MCP2D5N10Y`. **Confirm Qg from the datasheet** before committing — it is
the number that decides this and the one least reliably quoted.

### Switch A carries the most current and does no switching

```
  boost mode, D = 0.512
    A (buck HS)  ON CONTINUOUSLY    6.02 A  - no switching at all
    C (boost LS) conducts D         4.31 A rms
    D (boost HS) conducts 1-D       4.21 A rms
```

In boost mode the buck-side high side is simply held on, so it carries the full
inductor current and dissipates pure I²R. C and D carry less and take all the
switching loss. They are not interchangeable duties, even though one part number
covers all four positions.

### At 60 V, switching loss beats conduction loss

```
    Rds   A conducts        t_sw   C+D switching
   10m        0.36W         15 ns          1.08W
   25m        0.91W         20 ns          1.44W
   50m        1.81W         30 ns          2.17W
                            40 ns          2.89W
```

Switching energy scales with switching **time**, not with Rds(on) — and gate
charge is what sets the time. **A 10 mΩ part carrying 150 nC loses to a 25 mΩ
part carrying 40 nC.** Hence 20–30 mΩ and low Qg, rather than the lowest
resistance on the shelf.

### Gate charge is a ceiling, not a preference

```
  Qg  30 nC x 4 FETs at 200 kHz ->  24.0 mA and 0.15 W from INTVCC   ok
  Qg  50 nC x 4 FETs at 200 kHz ->  40.0 mA and 0.25 W from INTVCC   ok
  Qg 100 nC x 4 FETs at 200 kHz ->  80.0 mA and 0.51 W               check
  Qg 150 nC x 4 FETs at 200 kHz -> 120.0 mA and 0.76 W               check
```

Four FETs at 200 kHz is a real load on a controller's internal regulator. The
LT8705 has an **`EXTVCC` pin** — supply the gate drive externally and the
internal regulator stops being the constraint. Worth planning for rather than
discovering.

### Heatsinking, and the sensor that goes with it

```
  t_sw 15 ns:  A 0.91 W   C 1.01 W   D 0.98 W   B ~0   total 2.90 W/channel
  t_sw 30 ns:  A 0.91 W   C 1.55 W   D 1.53 W   B ~0   total 3.98 W/channel
```

About **3–4 W per channel** across four devices. Against an internal ambient
near 45 °C and Tj max 150 °C:

| package / mounting | θ | rise at 1.5 W | Tj |
|---|--:|--:|--:|
| DPAK, 1 in² copper | 40 °C/W | 60 °C | 105 °C |
| D2PAK, good copper | 25 °C/W | 38 °C | 82 °C |
| TO-220, clip heatsink | 20 °C/W | 30 °C | 75 °C |
| **TO-220, shared heatsink** | 8 °C/W | 12 °C | 57 °C |

A shared TO-220 heatsink is the easy answer for a hand build — and it is the
heatsink the [1-Wire probe](control.md#temperature-sensing-1-wire-and-isolated-by-the-packaging)
clamps to, which is why that sensor leads everything else in the box.

**All four tabs sit at different potentials**, so each needs its own insulator
on a shared sink. That is precisely why the sink floats at a channel potential,
and why the temperature probe has to be electrically isolated.

## The inductor

Hand-wound, one per channel. At the design point — 29.3 V in, 60 V out, 3 A,
200 kHz — it is **41.5 µH carrying 6.02 A DC with 1.81 A of ripple**, storing
1.00 mJ. (More inductance than the 3 A case, and less current: derating raises
L because the ripple budget is a fraction of a smaller DC current.)

### Powder cores lose permeability under DC bias, and it changes the answer

This is the trap. Size the turns from the datasheet AL and you get an inductor
that is right at no load and badly low exactly where it matters.
[`calc/core_choice.py`](calc/core_choice.py) solves the turns *against* the
biased permeability instead, iterating because more turns means more H means
more roll-off:

```
core OD x ID x H         mu      AL  mu left      N   fits one layer
24.5 x 15.8 x 12.7       60    66nH     68%     28     no
24.5 x 15.8 x 12.7      125   137nH     64%     20    yes
33 x 20 x 11             60    69nH     79%     25    yes
```

The unbiased calculation says 23 turns of 60µ at 25 mm. The biased one says
**28, which does not fit in one layer.** Same core, same target, and the naive
number would have been wound and then found wanting.

Those AL figures are worked out from the outside dimensions, which is fine for
choosing a size but not for winding one — see the 20 % Ae error below. The core
that was actually chosen is done properly, off the catalogue.

### The core: Magnetics **0077083A7** — Kool Mu 0254, 60µ

Ordering code confirmed from [the datasheet](datasheets/KoolMu-0077083A7.pdf),
which is in this repo because finding it was genuinely difficult. Note `083` is
the **ordering code**, not the core-data number — the core data is 0254, and
guessing the part number from it would have failed. Hence the DigiKey number
below: the search is the hard part, not the decision.

| | |
|---|---|
| Part | **0077083A7**, black coated, 61 g |
| DigiKey | **4616-0077083A7-ND** |
| Permeability | **60µ** |
| AL | **81 nH/T² ± 8 %** |
| Ae / le / Ve | 107 mm² / 98.4 mm / 10 600 mm³ |
| Dimensions | OD 40.77 max, ID 23.32 min, HT 15.37 max (coated) |
| Window | 427 mm² |
| Turns | **24** for 41.5 µH at 6.93 A peak — **wind 25 and measure** |
| Wire | **3 × AWG18** twisted, grade 2 heavy build, Class 180 (H) |
| Coating | continuous to 200 °C, Curie 500 °C |
| Hƒ variant | **drop-in** — see below |

Every figure the design was built on matches the datasheet exactly.

#### The DC bias curve is better than assumed — and it was the figure on trust

```
  datasheet minimums:  80% of initial mu at 39 Oe,  50% at 87 Oe
  the estimate used:   80% at 30 Oe,                50% at 80 Oe
```

The real core holds up **better** than the interpolation table assumed, and
those are minimums. At our 21.5 Oe that is **89 %** rather than 87, and the turn
count is unchanged at 24. `core_choice.py`'s 60µ curve is now anchored on these
two points; the other permeabilities in it remain estimates.

#### AL is ±8 %, which is why you wind long and measure

```
  AL high, 87.5 nH   -> 23.1 turns
  AL nominal, 81 nH  -> 24.0 turns
  AL low,   74.5 nH  -> 25.0 turns
```

**Two turns of spread from tolerance alone.** Wind 25, measure, remove one if it
reads high — which was the right instruction before the datasheet and is now the
demonstrably right one.

#### Losses, from the datasheet's own loss figure

```
  datasheet 750 mW/cm3 max at 100 kHz / 100 mT
  ours: 14.6 mT peak at 200 kHz  ->  0.37 W core
  plus                               0.33 W copper
                                     0.70 W total
```

Scaled from the datasheet's single point rather than from memory — the earlier
~0.6 W guess for core loss was close. Copper uses the datasheet's **winding
length per turn, 54.3 mm at 20 % fill** (its 0 % figure, 48.2 mm, equals
2 × (HT + (OD−ID)/2) exactly, which is a good check on the formula).

#### It fits the window with room to spare

24 turns of a 2.21 mm bundle is **92 mm² in a 427 mm² window — 22 % fill.** The
wound coil will come out around **OD 43, HT 19 mm** (the datasheet gives 44.3 /
22.4 at 40 % fill), which is what the enclosure has to accommodate.

**Use the catalogue's Ae, not the one you can work out from the outside.**
Cross-section from the dimensions gives 134 mm²; the catalogue says **107** —
20 % less, because the rounded edges that stop the core cutting the wire take
real iron away. That error put AL at 100 nH instead of 81 and would have had
this wound at 20 turns instead of 22.

```
  mu     AL    N       H  mu left      dB  bundle max      Cu    P_cu    Emax
  40    54n   29  26.1Oe      88%  23.8mT      2.24mm   1.55m   0.39W   105mJ
  60    81n   24  21.5Oe      87%  28.9mT      2.67mm   1.28m   0.32W    70mJ
  75   101n   22  19.4Oe      85%  32.0mT      2.92mm   1.15m   0.29W    56mJ
  90   121n   20  17.9Oe      84%  34.8mT      3.14mm   1.06m   0.27W    47mJ
 125   168n   17  15.4Oe      82%  40.3mT      3.57mm   0.92m   0.23W    34mJ
```

**What did not decide it: DC bias.** Every permeability lands at 80–85 %,
because higher µ needs fewer turns, which lowers H, which offsets the steeper
roll-off curve. On a smaller core that trade runs the other way and low µ wins
on stability — here it does not separate them.

**What decides it is ΔB.** Core loss scales roughly as ΔB^2.1, and Kool Mu's
loss coefficient rises with permeability as well, so the 0.12 W of copper that
125µ saves is paid back several times over in the core. Lower µ, lower ΔB, less
total loss. Check the vendor's loss curves for the magnitude; the direction is
not in doubt.

Energy capacity at 60µ is **70 mJ against 1.00 mJ needed** — 70× — so
saturation is nowhere near the binding constraint. The binding constraint is
loss.

### The Hƒ variant is a drop-in, and does not unlock a faster converter

Magnetics also list **Kool Mu Hƒ**, a lower-core-loss formulation. For core 0254
the two catalogue rows are identical where they overlap:

```
   mu  standard     Hf
  26u       35n    35n   identical
  40u       54n    54n   identical
  60u       81n    81n   identical
  75u ... 125u             not offered in Hf
```

le, Ae, Ve and the dimensions match as well, so **nothing in this design
changes** — same 24 turns, same 3 × AWG18. And Hƒ stopping at 60µ costs nothing
here, because 60µ is where the ΔB argument landed anyway. (26µ would need 37
turns and cap the bundle at 1.84 mm, so it will not take the wire.)

What it buys is perhaps 20–30 % off the core loss — roughly **0.15 W per
channel** against a 5–7 W loss budget. Worth having for free, worth nothing in
efficiency terms, and it runs a little cooler in a box already shedding ~100 W.

**What it does not buy is a higher switching frequency.** Hƒ earns its keep at
500 kHz–1 MHz, where core loss is the limit. Here the limit is MOSFET switching
loss — 4 W at 200 kHz against 10 W at 500 kHz — so a lower-loss core does not
move the ceiling. Choosing Hƒ *in order to* switch faster would be the wrong
reason.

**One thing to confirm if you take the Hƒ variant:** the standard part's bias
curve is now known from its datasheet (80 % at 39 Oe minimum), and the turn
count depends on it. Hƒ matching on AL does not guarantee it matches on bias.
For the standard `0077083A7` this is no longer an open question.

### The wire

```
winding         Cu mm2   bundle      DCR    P_dc    P_ac      J   fits
10 x AWG25       1.62   1.79mm   13.2mR   0.48W     4mW   3.7    yes
5 x AWG20        2.59   2.26mm    8.4mR   0.30W     4mW   2.3    yes
3 x AWG18        2.47   2.21mm    8.8mR   0.32W     5mW   2.4    yes
1 x AWG14        2.08   2.03mm   10.4mR   0.38W     8mW   2.9    yes
```

24 turns leaves room for a bundle up to **2.70 mm** in one layer, which is the
payoff for the bigger core — the drawer core's 15.8 mm hole allowed 1.79 mm.
That headroom is what drops the current density from 4.5 to 2.9 A/mm² and takes
a third off the copper loss for nothing.

**P_ac is milliwatts in every row, including solid AWG14.** The ripple is
0.52 A RMS against 6.02 A of DC — the AC is 9 % of the current, so skin effect
is not what sizes this wire. Strand it because 2.5 mm² of solid copper will not
bend round that hole twenty-two times. Three strands is the fewest that still
handles easily; twist them loosely and treat them as one wire. Cut ~1.3 m per
strand — 24 turns of a 52 mm mean turn is 1.28 m, plus tails and the slack for
the turn you may remove.

### The cores already in the drawer do not work

Worth writing down so it is not re-litigated:

| On hand | Why not |
|---|---|
| "T30-2", measured 24.5 × 15.8 × 12.7 | **T30 is an inch code — 0.30 in = 7.8 mm OD.** The measured core is 3× that in every dimension and 30× the volume, so it is not a T30 of anything. And Micrometals mix 2 is iron powder, not ferrite, so the label contradicts itself |
| …if it is really mix 2 (µ10) | 56 turns needed, 25 fit. µ10 is an RF material, far too low for a 35 µH power inductor in this window |
| …if it is Mn-Zn ferrite (µ~2000), which a 25 × 15 × 12 ring usually is | stores **0.11 mJ** against 1.00 mJ needed — saturates on the first switching cycle |
| green cores, also on hand, "a little smaller" | never measured. Green is usually a power material (Micrometals -52, or a sendust) and would probably work — but the call was to buy to the spec above rather than reverse-engineer the drawer |

**Keep the ferrite rings.** Two switching converters and 5.8 A of mains draw
will want a **common-mode choke**, and an ungapped high-µ ring is exactly right
for that job — no net DC flux, so none of the above applies.

### Securing it — not with rigid epoxy

**Do not pot it in rigid epoxy.** The strongest reason has nothing to do with
epoxy: hand-wound inductance never lands first time, and with the bias roll-off
above you will want to measure L *at current*, adjust turns and measure again.
Epoxy makes that a one-shot. Beyond that, rigid epoxy shrinks on cure and
expands far more than the core does, a pressed powder toroid is brittle, and the
shell traps the heat the core and copper have to shed. **Varnish the winding**
to lock the turns and hold the core with a cable tie, a nylon screw or a printed
saddle. If it must be potted later, use a compliant silicone or soft
polyurethane, after the design measures right.

## The 2 V end is the hard end, and the pre-regulator has to track

60 V is the number that sounds difficult. 2 V is the one that actually is:

```
fixed 40 V rail            drops 38.2 V at 3 A = 114.5 W   to deliver 6 W
tracking, +3 V above out   drops  3.0 V at 3 A =   9.0 W   to deliver 6 W
```

A linear pass stage hanging off a fixed rail is not a thermal design, it is a
heater. The switcher has to **follow the output** a few volts above it, with the
linear stage cleaning up only that last few volts. Dissipation then stays
roughly constant across the whole 30:1 range instead of peaking at the bottom.
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

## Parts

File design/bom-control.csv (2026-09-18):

Ref | Qty | Value | Description | Rating / key spec | Package | Suggested part | Notes
U1 | 1 | - | Raspberry Pi Pico | RP2040; 26 usable GPIO; 2x SPI; PIO | module | Raspberry Pi Pico | POWERED ON VSYS (PIN 39), NOT VBUS. VBUS is the USB connector's 5 V with nothing in between - driving it back-feeds the host. USB reaches VSYS through the on-board D1 so a cable can stay plugged in for programming
D1 | 1 | - | Schottky diode | 40 V; 1 A | SOD-123 | 1N5819 | In the 5 V feed to VSYS. Protects the module in the other direction; 5 V less the drop lands VSYS near 4.7 V, well inside its 1.8-5.5 V range
C1 | 1 | 470u | Electrolytic capacitor | 10 V; low ESR | radial | - | Bulk on the 5 V rail. Fans draw their worst at startup - all three at once if the box comes up hot
C2-C6 | 5 | 100n | Ceramic capacitor | 50 V; X7R | 0603 | - | Decoupling
R1;R2 | 2 | 10k | Pull-up resistor | 1% | 0805 | - | MISO pull-up, one per channel. THE ONLY ONE OF THE FIVE OPTO PULL-UPS THAT BELONGS ON THIS BOARD - the other four are in isolated domains on the converter boards
R3 | 1 | 4k7 | Pull-up resistor | 1% | 0805 | - | 1-Wire bus to 3V3
J1;J2 | 2 | - | Header - barrier drive | 6-pin; 2.54 mm | 2.54 mm | - | SCK MOSI CS_SW CS_AD MISO GND to each converter board. ALL PICO-REFERENCED - the optos are over there, so nothing on this cable is isolated or needs to be
J3 | 1 | - | Header - mains board | 6-pin; 2.54 mm | 2.54 mm | - | RLY_MAIN_A RLY_MAIN_B TRIG_A TRIG_B +5V GND. The Pico does NOT drive RLY_SOFT - it triggers the monostable that does
J4-J6 | 3 | - | Fan connector | 2-pin; 2.54 mm | 2.54 mm | - | All three fans are switched and temperature-staged. Fan 1 additionally has TS1 in parallel with its FET
D2-D4 | 3 | - | Flyback diode | 100 V; 1 A | SOD-123 | 1N4148 | ACROSS EVERY FAN. The 2N7002 driver board does not carry one, and it matters more with an AO3400's 30 V than a 2N7002's 60
Q1-Q3 | 3 | - | N-channel MOSFET - fan drive | 30 V; 28 mOhm at Vgs 4.5 V; true logic level | SOT-23 | AO3400A | On 2N7002 driver boards WITH THE FET SWAPPED. A 200 mA fan is 1.7x a 2N7002's 115 mA rating and 2-3x that at startup. Same G-S-D pinout - a transistor swap, not a redesign
- | 3 | - | 2N7002 driver board | 10.9 x 17.1 mm; M2 mount; 220R gate + 10k pulldown | - | hardware/2N7002 Driver | THREE - all three fans are Pico-staged on temperature. Fan 1's firmware-independent backstop is TS1, not a hardwired supply
TS1 | 1 | - | Bimetallic thermostat - normally open | closes 60-70 C; opens ~10 C lower; 5 A contacts | KSD9700 / bolt-on | - | IN PARALLEL WITH FAN 1's DRIVE FET. This is what lets fan 1 be software-controlled: normal staging is the Pico's, and if the Pico is halted or being reflashed TS1 runs the fan directly at 65 C. Sits above fan 3's threshold on purpose - if staging works at all it never closes. Mount on the same heatsink as the 1-Wire probe
J7 | 1 | - | Header - 1-Wire | 3-pin; 2.54 mm | 2.54 mm | - | 3V3 DQ GND to three DS18B20 probes in parallel
- | 3 | - | DS18B20 temperature probe | stainless; 12-bit; 3 m lead | probe | - | ELECTRICALLY ISOLATED BY CONSTRUCTION - which is the point. The heatsinks sit at their own channels' grounds and are up to 60 V apart when stacked; a metal-cased sensor on each would bridge the channels. Good for 60 V - not safety insulation
U2 | 1 | MCP23017 | 16-bit I2C GPIO expander | 1.8-5.5 V; 2 x 8 bit; interrupt outputs | SSOP-28 / SOIC-28 | MCP23017-E/SS | OPTIONAL - fit it when the GPIO budget runs out, which is now. Shares the display's I2C bus so it costs ZERO pins. Move RLY_MAIN x2, the NE556 triggers x2 and the three fan drives onto it: 26 GPIOs used becomes 19. NOT the encoders - quadrature needs prompt reads. Same part as TritonECU's 0x20
J8 | 1 | - | Header - display | 4-pin I2C; 2.54 mm | 2.54 mm | - | SSD1306-class. OPEN - see docs/control.md
J9;J10 | 2 | - | Header - rotary encoder | 5-pin; 2.54 mm | 2.54 mm | - | A B push per channel. 8 GPIOs between the two of them and there is ONE spare on the Pico
J11 | 1 | - | Terminal block - 5 V in | 2-pin; 5.08 mm | PCB | - | From the 5 V module on the back wall. Always on with the rocker - it powers the Pico that closes the relays and the fan that runs whenever the box is powered

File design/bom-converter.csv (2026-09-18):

Ref | Qty | Value | Description | Rating / key spec | Package | Suggested part | Notes
U1 | 1 | LT8705 | Synchronous 4-switch buck-boost controller | 2.8-80 V in; 1.3-80 V out; 100-400 kHz; quad N-ch drivers; four servo loops | QFN-38 / TSSOP-38 | LT8705EFE | 60 V out rules out LM5176 (55 V) and leaves LT3790 at exactly its limit. 80 V gives 20 V of margin on both sides
QA-QD | 4 | - | N-channel MOSFET | 100 V; 20-30 mOhm; Qg <= 50 nC | DPAK / D2PAK / TO-220 | STD26NF10 or STP40NF10L | CONFIRM Qg FROM THE DATASHEET - it is the binding parameter and the least reliably quoted. At 60 V switching loss beats conduction loss, so a 10 mOhm part at 150 nC loses to a 25 mOhm part at 40 nC
L1 | 1 | 41.5 uH | Hand-wound toroidal inductor | AL 81 nH/T2 +/-8%; Ae 107 mm2; le 98.4 mm; Ve 10600 mm3; 60u | 40.77 OD x 23.32 ID x 15.37 HT | Magnetics 0077083A7 (DigiKey 4616-0077083A7-ND) | 24 turns of 3 x AWG18 twisted. WIND 25 AND MEASURE - the +/-8% AL is two turns of spread on its own. Custom footprint: two pads plus a keepout for a 43 mm wound coil
- | 3 | - | Magnet wire AWG18 | grade 2 heavy build; Class 180 (H) | - | - | ~1.3 m per strand. Stranded so it bends round a 23 mm hole - NOT for skin effect: the AC is 9% of the current and P_ac is milliwatts even in solid AWG14
Cin | 4 | 10u | Ceramic capacitor | 100 V; X7R | 1210 | - | AT THE FETS AND SHORT. This is what makes splitting the rectifier onto its own board safe - Cin takes all the di/dt, the bulk caps only refill it
Cout | 2 | 470u | Polymer / low-ESR electrolytic | 100 V | radial | - | With the ceramics below gives ~130 uF for 50 mV of boost-mode ripple at 2.5 A
Cout_c | 4 | 22u | Ceramic capacitor | 100 V; X7R | 1210 | - | High-frequency half of the output bank
Rsen_IN | 1 | 5 mOhm | Current sense resistor | 1 W; 1%; 4-terminal preferred | 2512 | - | 50 mV at 7.4 A = THE INPUT CURRENT LIMIT. This is what stops the transformer being overdrawn and makes the 150 W envelope a hardware property
Rsen_OUT | 1 | 15 mOhm | Current sense resistor | 0.5 W; 1%; 4-terminal preferred | 2512 | - | 50 mV at 3 A = the user-set CC limit. KELVIN both sense pairs from the pad ends, not from the power path
Rtop | 1 | 48.7k | Precision resistor | 0.1%; 25 ppm | 0805 | - | Sets the whole divider ratio against FBOUT's 1.207 V
Rfix | 1 | 75k | Precision resistor | 0.1% | 0805 | - | THE FIXED BRANCH. Sets 2 V with every switch OPEN - unpowered, in reset, mid-reflash. Wire the switches to ADD conductance only
R0-R9 | 10 | 1M05 523k 261k 130k 64k9 32k4 16k2 8k06 4k02 2k00 | Divider branch resistors - binary weighted | 0.1%; 25 ppm | 0805 | - | E96 nearest to the ideal binary conductances; branch errors 0.0-1.3%. Steps stay near-uniform and the Pico calibrates code-to-volts from its own ADC readback at bring-up
U2;U3 | 2 | ADG714 | Octal SPST analog switch - SPI | 2.5 Ohm on-resistance; 2.7-5.5 V | TSSOP-20 | ADG714BRUZ | IS the serial-to-parallel converter AND the switch array. 2.5 Ohm is 0.25% error at 60 V where Rbot is 1k; a CD4051 at 100 Ohm would be 10%. VERIFY THE POWER-UP STATE IS ALL-SWITCHES-OPEN
U4 | 1 | - | SPI ADC | 12-bit; 4 channel | SOIC-14 | MCP3204 | Vout divider, Iout, Iin, and the SRVO_* loop-status pins so the Pico can display CV / CC / input-limited
U5;U6 | 2 | INA293 | High-side current sense amplifier | >= 80 V common mode; gain 50 | SOT-23-8 | INA293A2 | THE COMMON MODE IS THE OUTPUT and it goes to 60 V. A garden-variety 26 V part will not do
OK1-OK5 | 5 | - | Optocoupler | CTR >= 80% at If 5 mA; 5 kV isolation | DIP-4 / SOP-4 | PC817 | FOUR OUT with LEDs on the Pico side (SCK MOSI CS_SW CS_AD) and ONE BACK with its LED on THIS side (MISO). Nothing electrical bridges the gap - these channels stack in series
- | 5 | 330R | Opto LED resistor | 1% | 0805 | - | If = 5 mA from a 3.3 V GPIO. RP2040 sources 12 mA max
- | 5 | 10k | Opto pull-up | 1% | 0805 | - | Sets the edge rate. Tens of microseconds - run the SPI clock at a few kHz, not at SPI speeds
U7 | 1 | - | 60 V buck regulator | 44 V in; 12 V out; ~100 mA | - | - | Local bias from THIS channel's own rail. NOT from the control board's 5 V - that would wire the two channels together and undo the isolation
U8 | 1 | - | 5 V LDO | 12 V in; 5 V out; 100 mA | SOT-223 | - | Feeds ADG714 ADC INA and the opto pull-ups
- | 1 | - | EXTVCC feed | 12 V from U7 | - | - | Qg x 4 x 200 kHz is 24-40 mA out of INTVCC. Feeding EXTVCC externally takes the internal regulator out of the argument
Rg1-Rg4 | 4 | 2R2 | Gate resistor | 1% | 0805 | - | Damps the gate ring. Bigger slows switching and switching TIME is what costs at 60 V
Cb1;Cb2 | 2 | 100n | Bootstrap capacitor | 100 V; X7R | 0603 | - | BOOST1 to SW1 and BOOST2 to SW2
Db1;Db2 | 2 | - | Bootstrap diode | 100 V; fast | SOD-123 | - | To GATEVCC
D_rev | 1 | - | Reverse protection diode | 100 V; >= 3 A | - | - | ACROSS the output - anti-parallel, cathode to +, reverse-biased in normal use and carrying nothing. Only conducts if the other channel drives this one backwards while it is off or shorted. NOTHING GOES IN SERIES WITH THE OUTPUT
TB1 | 1 | - | Terminal block | 100 V; 15 A; 7.5 mm | PCB | - | DC rail in from the rectifier board
TB2 | 1 | - | Terminal block | 100 V; 10 A; 7.5 mm | PCB | - | Output to the front panel
J1 | 1 | - | Header - opto barrier | 6-pin | 2.54 mm | - | SCK MOSI CS_SW CS_AD MISO GND to the control board

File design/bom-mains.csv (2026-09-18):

Ref | Qty | Value | Description | Rating / key spec | Package | Suggested part | Notes
J1 | 1 | - | IEC C14 inlet + rocker + fuse drawer | 10 A 250 V; 58 x 48 face; 50 x 29 x 19 rear flange; M3 ears at 40 mm | panel | BIQU 10 A 250 V | Back wall. Its terminals are the reason the printed shield exists
F0 | 1 | 10 A T | Cartridge fuse 5 x 20 mm | 250 V time-delay | in J1's drawer | - | Carries 5.99 A with both channels at full output. 10 A is ALSO the inlet's own ceiling - no room above it
F1;F2 | 2 | 5 A T | Cartridge fuse 5 x 20 mm | 250 V time-delay | 5 x 20 | - | One per toroid primary; 2.92 A each. 4 A derates to 3.6 at 45 C and blows on a warm day
F3 | 1 | 1 A T | Cartridge fuse 5 x 20 mm | 250 V time-delay | 5 x 20 | - | 5 V control module; 0.16 A. 5.6x margin
FH1-FH3 | 3 | - | PCB fuse holder 5 x 20 mm | 250 V; >= 10 A | PCB | - | MAINS CANNOT USE BLADE FUSES - 120 VAC needs a 250 V cartridge
RLY_MAIN | 2 | - | Power relay SPST-NO | 10 A 250 VAC contacts; 5 V coil ~80 mA; >= 4 kV coil-to-contact | PCB | - | Closes into an ALREADY ENERGISED transformer so it never sees inrush. A proper mains part - not a signal relay printing 250 V on the contacts
RLY_SOFT | 2 | - | Power relay SPST-NO | 5 A 250 VAC contacts; 5 V coil ~80 mA; >= 4 kV coil-to-contact | PCB | - | Carries 2.92 A for 300 ms only and closes into inrush already limited to 17 A - can be the smaller part
R1;R2 | 2 | 10R | Wirewound resistor | 20 W; non-inductive preferred | chassis or PCB power | - | Soft start. 85 W while in circuit - fine as a 0.3 s pulse (26 J) and fatal if it never ends. Hence the one-shot below
U1 | 1 | NE556 | Dual timer - monostable | 5 V supply | DIP-14 / SO-14 | NE556 | ONE-SHOT per channel driving RLY_SOFT. This is the whole safety argument: RLY_SOFT drops out by itself whether or not RLY_MAIN closed
R3;R4 | 2 | 270k | Timing resistor | 1% | 0805 | - | t = 1.1 x R x C = 297 ms with C = 1u
C1;C2 | 2 | 1u | Timing capacitor | film or C0G; 10 V | 0805 | - | Not electrolytic - the period should not drift with age or temperature
D1-D4 | 4 | - | Flyback diode | 100 V; 1 A | SOD-123 / DO-41 | 1N4007 | ACROSS EVERY COIL. A relay coil is far more inductive than a fan and the 2N7002 driver board does not carry one
Q1-Q4 | 4 | - | N-channel MOSFET - coil drive | 30 V; 28 mOhm at Vgs 4.5 V; true logic level | SOT-23 | AO3400A | On the 2N7002 driver boards WITH THE FET SWAPPED. 80 mA is most of a 2N7002's 115 mA rating before the turn-off spike
- | 4 | - | 2N7002 driver board | 10.9 x 17.1 mm; M2 mount; 220R gate + 10k pulldown | - | hardware/2N7002 Driver | Keep the boards - the 10k pulldown holds the gate off while the Pico's GPIOs are high-impedance during boot
TB1-TB3 | 3 | - | Mains terminal block | 300 V; 10 A; 5.08 mm | PCB | - | Two toroid primaries and the 5 V module's ACL/ACN
E1 | 1 | - | Earth stud / ring terminal | M4 | chassis | - | C14 earth pin to the supply earth terminals - star point. The enclosure is plastic but the pin still has to go somewhere

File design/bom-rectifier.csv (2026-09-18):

Ref | Qty | Value | Description | Rating / key spec | Package | Suggested part | Notes
F1 | 1 | 20 A | Blade fuse | 58 V TYPE - not standard 32 V | ATO/ATC | - | Secondary. Winding carries 10.1 A rms; 20 A derated to the automotive 75% is 15 A continuous
F2 | 1 | 15 A | Blade fuse | 58 V TYPE - not standard 32 V | ATO/ATC | - | DC rail. 6.02 A carried. Cannot save a shorted FET - it stops the bulk bank emptying into the wreckage afterwards
FH1;FH2 | 2 | - | Blade fuse holder | PCB or inline; >= 30 A | - | - | STANDARD BLADE FUSES ARE 32 VDC AND THIS RAIL REACHES 44.3 V. Above rating the arc does not self-extinguish: the fuse does not clear, it keeps burning
BR1 | 1 | - | Bridge rectifier | 35 A; 200 V; bolt-down | GBPC / KBPC | GBPC3502 | ~12 W - two diodes conduct in series at all times. NEEDS A HEATSINK. Not a DIP bridge
HS1 | 1 | - | Heatsink for BR1 | <= 5 C/W | - | - | 12 W is the same class of heat as the whole FET bank
C1-C4 | 4 | 4700u | Electrolytic capacitor | 63 V; 105 C; low ESR; snap-in | snap-in | - | PARALLELED FOR RIPPLE CURRENT NOT CAPACITANCE. 8800 uF covers the ripple voltage but a cap-input filter puts 9-12 A rms through them and one can is rated 3-4 A
R1 | 1 | 4k7 | Bleeder resistor | 1 W | axial | - | 18800 uF at 40 V holds 15 J that stays there after power-off with the converter unplugged. 40 V is not a shock hazard; 15 J into a dropped tool still is
TB1 | 1 | - | Terminal block | 300 V; 20 A; 7.5 mm | PCB | - | 28 VAC in from the toroid secondary - gray 14 AWG
TB2 | 1 | - | Terminal block | 100 V; 15 A; 7.5 mm | PCB | - | DC rail out to the converter. Heavy pair but its inductance does not matter - 6 A dc with 120 Hz ripple is not a switching loop

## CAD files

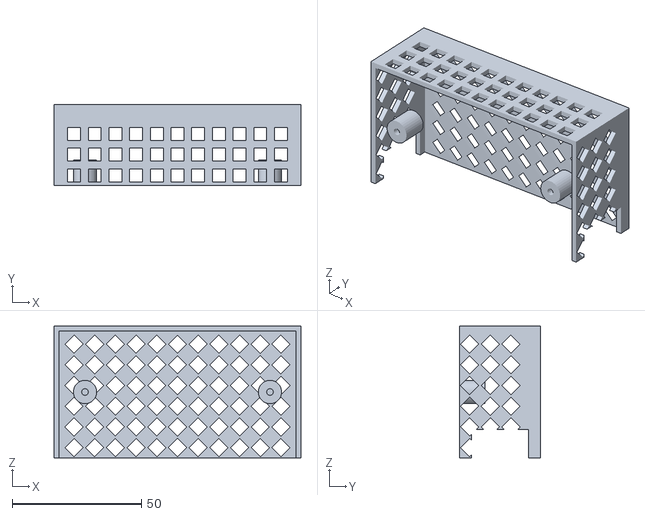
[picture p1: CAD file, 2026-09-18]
stl/psu5_shell.stl
95.5 x 31.5 x 51.0

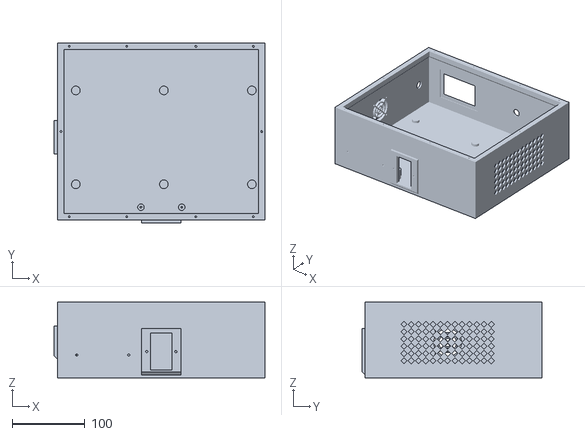
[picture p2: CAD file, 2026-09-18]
stl/tub.stl
290.0 x 247.0 x 104.0

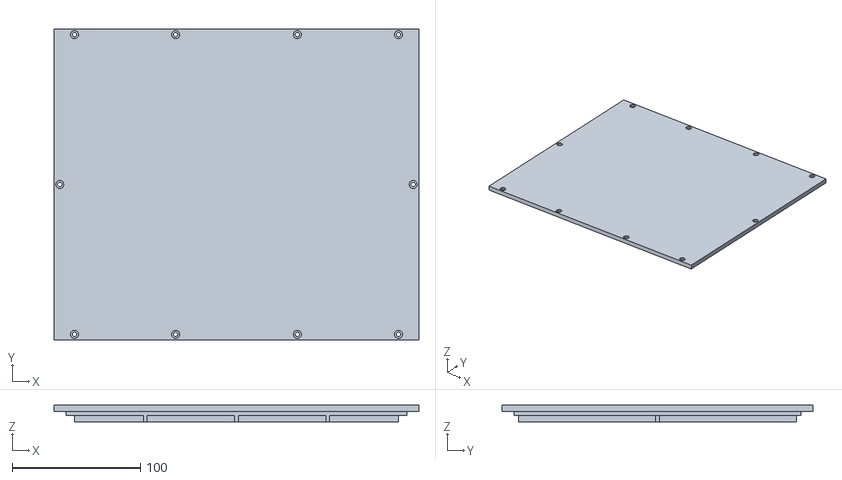
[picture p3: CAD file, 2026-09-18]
stl/lid.stl
285.0 x 243.0 x 13.0

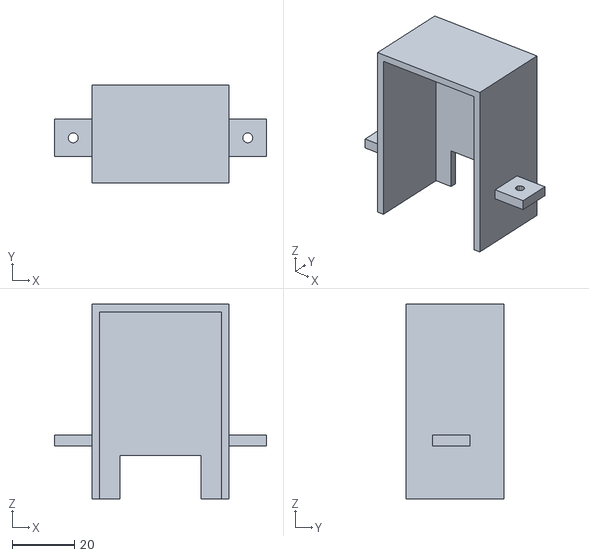
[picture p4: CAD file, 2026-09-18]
stl/shield.stl
68.0 x 31.5 x 62.5

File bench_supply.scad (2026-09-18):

// TritonECU — BenchSupply
// The bench power-supply enclosure, forked from TritonECU/hardware/psu-enclosure
// as the version to GROW: the supply is the first occupant, not the only one.
// The wiring bay was the room left for that, and the first thing to take some
// of it is the DC-DC module below — 5 V for the VR rig's Pico off the 36 V
// supply, plus an adjustable bench rail. What is left of the bay, and the space
// over the supply under the rim band, is still free.
//
// Mains inside a printed box. Read the safety note in README.md before you
// energise it: the lid screws are the only thing between a finger and 120 V.
//
//   render: part = "tub" | "lid" | "shield" | "psu5_shell" | "assembly"

part = "assembly";

/* Tessellation. Same reasoning as the VR rig: chord error is r*(1-cos(180/n)),
   so a 3.2 mm hole at fn 16 is off by 0.03 mm — below what the printer
   resolves. Spend facets only where a fit depends on them. The grid is cubes,
   which cost no facets at all, so it can be as dense as it likes. */
$fn      = 32;   // general
hole_fn  = 16;   // screw clearance and pilot holes
fit_fn   = 64;   // fan bore and guard, cable gland

/* ---------------------------------------------------------------------------
   MEASURE THESE before printing — everything else is derived from them
   --------------------------------------------------------------------------- */
psu_l           = 266;   // MEASURE: supply length  (the 266 minimum)
psu_w           = 153;   // MEASURE: supply width   (the 153 minimum)
psu_h           =  77;   // MEASURE: supply height  (the 77 minimum)

/* The supply's own mounting holes. There is no standard pattern, so the default
   below is THREE PADS A SIDE AT SENSIBLE PLACES, not a real bolt circle — they
   hold the supply up off the floor for airflow and nothing more. Measure the
   feet, edit standoff_xy, then set standoff_hole = true. */
standoff_hole   = false; // MEASURE the foot pattern first, then turn this on
standoff_screw  =   4.3; // M4 clearance
standoff_cbore  =   9.0; // head recess on the OUTSIDE of the floor
standoff_cbore_h=   2.6;
standoff_d      =  12;
standoff_h      =   4;   // the air gap under the supply

/* ---------------------------------------------------------------------------
   Shell
   --------------------------------------------------------------------------- */
wall     = 3;
/* DOUBLED from 3 for the toroidal transformers. Not for strength - the stress
   was never near anything, even at 3 mm. For stiffness: 5.8 kg of iron bows a
   3 mm floor 2.1 mm, which a box standing on four rubber feet rocks on, and
   creep settles that bow in permanently. 6 mm is 8x the stiffness and gets it
   to 0.27 mm. docs/calc/floor.py has the arithmetic.
   It does NOT fix the bolt: each toroid still hangs off one central screw, and
   that is a bearing problem. Put a steel spreader under the floor. */
floor_t  = 6;
lid_t    = 5;

/* Clearances. The fan end gets a real plenum: a 40 mm fan blowing into a 3 mm
   slot just stalls against the end of the supply. 10 mm lets the air turn and
   split between the 4 mm gap under the supply and the space over it. */
clr_fan  = 10;   // plenum, fan end
clr_grid =  3;   // exhaust end
/* The BACK long wall. It used to be 3 mm - the wall the supply was simply
   pressed against, and the only wall in the box with nothing in it. The mains
   inlet has moved onto it, so it now has to hold the inlet's 24 mm of flange
   and terminals plus the shield over them: 31.5 mm, and 34 leaves 2.5 mm to
   the supply.

   It is cheaper here than it was at END B. There the shield's 44 mm WIDTH had
   to fit across the bay; on a long wall the width runs along the wall, which
   is free, so only the depth costs anything. 50 at END B, 34 here. */
bay_back = 34;

/* The wiring bay. It used to be 39, set by the IEC module's rear flange on the
   long side. The plug has since moved to END B, and what sets the width now is
   the SHIELD over its terminals: 29 mm of flange, clearance for booted spades
   either side, and a wall each side comes to 44, which a 39 mm bay cannot hold.

   50 costs 11 mm of box width and gives it back twice over — with the plug off
   the long side there is 24.6 mm behind the DC-DC without any boss at all, so
   mod_boss goes to 0 and the external bump on that wall disappears. The bed
   footprint is unchanged either way. */
bay_w    = 50;

/* ---------------------------------------------------------------------------
   Lid seat
   ---------------------------------------------------------------------------
   The lid screws CANNOT land in corner posts: with 3 mm of clearance beside the
   supply there is nowhere to put a post. So the screws go into a band that
   thickens the wall inward around the whole top rim, sitting entirely ABOVE the
   supply where the volume is free anyway. The band's underside is a 45 degree
   taper (rim_taper = rim_w), so it prints with no support and no drooping
   ledge, and its inner face doubles as the rabbet the lid locates in. */
rim_w     = 6;       // how far the band comes inward
rim_taper = rim_w;   // 45 degrees. Keep these equal.
head      = 2;       // gap between the supply's top and the start of the taper
boss_d    = 9;       // screw engagement depth in the band
lid_screw = 2.6;     // M3 cutting its own thread. Heat-set insert? use 4.2.
lid_clr   = 3.4;     // M3 clearance through the lid
lid_cbore = 6.4;     // socket head recess
lid_cbore_h = 3.2;

/* ---------------------------------------------------------------------------
   Derived box
   --------------------------------------------------------------------------- */
in_l  = clr_fan + psu_l + clr_grid;
in_w  = bay_back + psu_w + bay_w;
in_h  = standoff_h + psu_h + head + rim_taper + boss_d;

out_l = in_l + 2*wall;   // 285
out_w = in_w + 2*wall;   // 201
out_h = floor_t + in_h;  // 101

/* Supply's own corner, in box coordinates. */
psu_x0 = wall + clr_fan;
psu_y0 = wall + bay_back;
psu_z0 = floor_t + standoff_h;
psu_top = psu_z0 + psu_h;

rim_z0 = psu_top + head;      // taper starts
rim_z1 = rim_z0 + rim_taper;  // band is full width from here up

standoff_xy = [ for (x = [psu_x0 + 12, psu_x0 + psu_l/2, psu_x0 + psu_l - 12],
                     y = [psu_y0 + 12, psu_y0 + psu_w - 12]) [x, y] ];

/* ---------------------------------------------------------------------------
   40 x 40 x 10 fan — END A (x = 0), blowing IN
   ---------------------------------------------------------------------------
   Mounted OUTSIDE the wall. Inside would cost 10 mm of a 10 mm plenum and the
   supply is only 10 mm away. The pad gives the M3s 8 mm of plastic to cut into
   instead of 3, and its underside is drafted at 45 so it needs no support. */
fan_sq       = 40;
fan_pitch    = 32;    // bolt centres, from the drawing
fan_screw    =  2.6;  // M3 self-tapping through the fan's own 3.5 mm holes
fan_bore     = 38;
fan_pad      = 46;
fan_pad_t    =  5;
fan_guard    = true;  // concentric webs over the bore
fan_web      =  2.0;

fan_cy = psu_y0 + psu_w/2;
fan_cz = psu_z0 + psu_h/2;

/* ---------------------------------------------------------------------------
   Exhaust grid — END B (x = out_l)
   ---------------------------------------------------------------------------
   Squares turned 45 degrees. A square hole in a vertical wall has a flat top
   edge that has to bridge; a diamond has an apex, so every hole is
   self-supporting and there is nothing to droop into the airstream. */
grid_pitch = 10;
grid_sq    =  6;   // side. Across the corners that is 8.49, leaving 1.5 of rib.
grid_inset =  8;   // keep the grid inside the supply's shadow

/* ---------------------------------------------------------------------------
   IEC C14 inlet / switch / fuse module — BACK WALL (y = 0)
   ---------------------------------------------------------------------------
   Moved again, and this is where it belongs: the back long wall is the one
   surface with nothing else on it, so the mains gets a wall to itself and the
   front wall is all low voltage - the DC-DC's screen, its knob, the outputs.
   Cord out the back, controls at the front.

   That wall was blank because it had no depth; bay_back is what buys it. END B
   goes back to being nothing but exhaust grid, which is better for the air.

   Still 58 mm axis VERTICAL, so the rocker is at the top and the fuse drawer
   pulls out below it. Low, because the shield stands on the floor and uses the
   floor as the fourth side of its wire slot. */
plug_cut_l     = 50;   // flange, along Z
plug_cut_w     = 29;   // flange, along X
plug_clr       =  0.6;
plug_hole_pitch= 40;   // ear centres, along X
plug_hole_d    =  3.2;
plug_pad_w     = 54;   // along the wall. Bezel is 48 - pad it out
plug_pad_z     = 64;   // bezel is 58 tall
plug_pad_t     =  4;   // 4 + 3 = 7 mm of thread for the ear screws
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

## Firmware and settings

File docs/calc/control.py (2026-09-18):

#!/usr/bin/env python3
"""Setpoint divider, the optocoupler barrier, and the fan staging.

The regulator closes its own loop in hardware. The Pico only moves the
feedback divider, and everything here is about doing that across an isolation
barrier without giving the barrier away or commanding full output when the
firmware is not running.
"""
import math

# ---- the divider -----------------------------------------------------------
VMIN, VMAX, VREF, RTOP = 2.0, 60.0, 1.207, 48.7e3   # LT8705 FBOUT
Gmin, Gmax = (VMIN/VREF-1)/RTOP, (VMAX/VREF-1)/RTOP
print("=== Setpoint divider: Vout = Vref*(1 + Rtop*G) ===")
print(f"  Vref {VREF} V, Rtop {RTOP/1e3:.0f}k")
print(f"  Rbot {1/Gmax/1e3:.2f}k at {VMAX} V  ...  {1/Gmin/1e3:.2f}k at {VMIN} V")
print(f"  conductance {Gmax*1e6:.0f} uS ... {Gmin*1e6:.1f} uS")
print("  Vout is LINEAR in bottom-leg conductance, so binary-weighted parallel")
print("  resistors give uniform voltage steps - no lookup table.\n")
print(f"{'bits':>5} {'step':>9} {'branches':>9}")
for n in (8, 10, 12):
    print(f"{n:>5} {(VMAX-VMIN)/(2**n-1):>7.3f} V {n:>9}")

print("\n  Switch the BOTTOM leg only: the top leg sits at Vout and no analog")
print("  switch wants 60 V across it. Ron is in series with each branch, so it")
print("  hurts most where the branch is smallest - the high-voltage end:")
for ron in (5, 50, 100):
    print(f"    Ron {ron:>3} ohm -> {ron/(1/Gmax)*100:5.2f}% at {VMAX} V,"
          f" {ron/(1/Gmin)*100:5.2f}% at {VMIN} V")

print("""
=== Fail-safe direction ===
  Switches OPEN must mean MINIMUM output. Size the FIXED branch for 2 V and
  let the switches ADD conductance to climb. Then a Pico that is unpowered,
  in reset, or mid-reflash leaves 2 V on the terminals.
  Wire it the other way and a dead Pico commands 60 V into whatever is
  plugged in, with 8 A of inductor behind it.""")

# ---- the barrier -----------------------------------------------------------
BITS, CH = 10, 2
print(f"\n=== The optocoupler barrier ===")
print(f"  {BITS} bits x {CH} channels = {BITS*CH} switch lines.")
print(f"  One opto per line = {BITS*CH} optos, {BITS*CH} LED resistors,"
      f" {BITS*CH} pull-ups = {BITS*CH*3} parts.")
print(f"  SERIALISE instead: a shift register on the isolated side, and only")
print(f"  CLK + DATA + LATCH cross the barrier.")
print(f"    {3} optos per channel out, +1 back for readback = {4*CH} total.")
print(f"    {BITS*CH*3} parts -> about {4*CH*3} - a {BITS*CH*3/(4*CH*3):.1f}x saving.\n")

VDD_PICO, VF, VDD_ISO = 3.3, 1.2, 5.0
for IF_MA in (5, 10):
    R = (VDD_PICO - VF)/(IF_MA/1000)
    print(f"  If {IF_MA:>2} mA -> LED resistor {R:.0f} ohm"
          f"  (RP2040 GPIO sources 12 mA max)")
for ctr in (0.8, 0.4):
    ic = 5 * ctr
    for pull in (1e3, 10e3):
        need = VDD_ISO/pull*1000
        print(f"    CTR {ctr*100:>3.0f}% at If 5 mA -> Ic {ic:.1f} mA;"
              f" {pull/1e3:.0f}k pull-up needs {need:.1f} mA -> {ic/need:.0f}x margin")
print("""
  Optos are slow - tens of microseconds with a 10k pull-up - and here that
  costs nothing: the setpoint changes when a human turns a knob. But it does
  cap the shift clock. Run it at a few kHz, not at SPI speeds; 10 bits then
  takes single-digit milliseconds.

  Power-on: an RC reset on the shift register's clear pin puts all outputs at
  0 before the Pico says anything, which is 2 V out. If the isolated side ever
  browns out the register clears and the output FALLS. Both safe directions.

  Readback crosses the SAME barrier. Measuring V and I for a display means an
  ADC on the isolated side and its data coming back through one more opto -
  share the clock with the shift register and it costs one part per channel.""")

# ---- what NOT to use --------------------------------------------------------
print("\n=== Why not a linear digipot as the bottom leg ===")
RPOT, TAPS = 50e3, 256
step_r = RPOT/(TAPS-1)
vout = lambda rb: VREF*(1+RTOP/rb)
print(f"  {RPOT/1e3:.0f}k, {TAPS} taps -> {step_r:.0f} ohm per tap")
for rb in (1.0e3, 5.0e3, 49.33e3):
    print(f"    at {vout(rb):>5.1f} V  one tap moves it"
          f" {abs(vout(rb)-vout(rb+step_r)):>7.3f} V")
lo = abs(vout(49.33e3)-vout(49.33e3+step_r)); hi = abs(vout(1e3)-vout(1e3+step_r))
print(f"  step spread {hi/lo:.0f}:1 - Rbot is linear in tap, Vout goes as 1/Rbot.")
print("  The binary-weighted array is uniform at the same bit count, and its")
print("  switches-open state is the safe one for free. A DAC fixes linearity")
print("  but its reset output is an END of the range, not the safe end.")

print("\n=== Serial switches vs a shift register + discrete switches ===")
for ron, part in ((2.5, "ADG714-class octal SPST, SPI"), (100.0, "CD4051-class mux")):
    print(f"  Ron {ron:>5.1f} ohm ({part})"
          f" -> {ron*Gmax*100:5.2f}% error at {VMAX} V")
print("  The serial switch IS the serial-to-parallel converter. One part.")

# ---- readback ---------------------------------------------------------------
print("\n=== Readback across the barrier ===")
out = ["SCK","MOSI","CS_switches","CS_adc"]; back = ["MISO"]
print(f"  out  {len(out)} optos: {', '.join(out)}")
print(f"  back {len(back)} opto : {', '.join(back)}")
print(f"  {len(out)+len(back)} per channel, {2*(len(out)+len(back))} total")
print("  SPI, not I2C: optos are unidirectional and I2C's SDA is not.")
print("  Switch state is free - the daisy-chain output returns the PREVIOUS")
print("  word on the MISO opto already there for the ADC, so the Pico can")
print("  check that what it sent is what latched.")
I = 2.5      # derated from 3.0
print(f"\n{'shunt':>8} {'V at 3A':>9} {'P':>8} {'gain for 3.3V':>14} {'12-bit LSB':>12}")
for r in (0.010, 0.020, 0.050):
    v=r*I; print(f"{r*1000:>6.0f}m {v*1000:>7.1f}mV {I*I*r*1000:>6.0f}mW"
                 f" {3.3/v:>13.0f} {I/4096*1000:>10.2f}mA")
print("  20 mohm + gain 50 -> 3.0 V full scale, a stock INA gain.")
print("  High-side sense sees up to 60 V common mode: INA293-class, not 26 V.")
print("  And the Pico must not ENFORCE the current limit - CC needs an analog")
print("  error amp diode-OR'd into the same FB node. The Pico sets the")
print("  threshold; hardware acts on it.")
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

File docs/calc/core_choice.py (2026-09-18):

#!/usr/bin/env python3
"""Pick the inductor core and its winding.

Two things here that a naive calculation gets wrong:

1. Powder cores lose permeability under DC bias. Size the turns from the
   datasheet AL and the inductor is right at no load and low where it matters.
   The turns are solved AGAINST the biased permeability, iterating, because
   more turns means more H means more roll-off.

2. Ae worked out from the outside dimensions is about 20% optimistic. The
   rounded edges that stop the core cutting the wire take real cross-section
   away. Measured against the Kool Mu catalogue for core 0254 below - use
   catalogue data whenever you have it.
"""
import math
MU0 = 4*math.pi*1e-7

# ---- the operating point (docs/power-chain.md) ------------------------------
L_TARGET = 41.5e-6          # H, wanted AT PEAK CURRENT, 200 kHz
I_DC, I_PK, DI = 6.02, 6.93, 1.81   # 60 V x 2.5 A, derated from 3.0
I_AC = DI/math.sqrt(12)
I_RMS = math.sqrt(I_DC**2 + I_AC**2)
RHO, DELTA = 1.72e-8, 0.148          # copper; skin depth in mm at 200 kHz

# Kool Mu DC-bias roll-off, % of initial permeability vs H in Oersted.
# Read off the vendor's DC bias curves - confirm for the exact part.
BIAS = {
 40:  [(0,100),(10,97),(20,92),(30,86),(50,74),(80,58),(120,42)],
 # 60u is anchored on the 0077083A7 datasheet: 80% at 39 Oe, 50% at 87 Oe,
 # both MINIMUMS, so a real core does better. The others are still estimates.
 60:  [(0,100),(20,90),(39,80),(60,66),(87,50),(120,38)],
 75:  [(0,100),(10,93),(20,85),(30,77),(50,61),(80,46),(120,32)],
 90:  [(0,100),(10,92),(20,82),(30,73),(50,57),(80,42),(120,29)],
 125: [(0,100),(10,88),(20,76),(30,66),(50,50),(80,35),(120,24)],
}
def mu_frac(mu, H_oe):
    pts = BIAS[mu]
    if H_oe <= 0: return 1.0
    for (h0,p0),(h1,p1) in zip(pts, pts[1:]):
        if H_oe <= h1: return (p0 + (p1-p0)*(H_oe-h0)/(h1-h0))/100
    return pts[-1][1]/100

def turns(AL_nH, le_mm, mu):
    """Solve N against the biased permeability."""
    N = math.sqrt(L_TARGET/(AL_nH*1e-9))
    for _ in range(80):
        H = (N*I_PK/(le_mm*1e-3))/79.577
        N = math.sqrt(L_TARGET/(AL_nH*1e-9*mu_frac(mu, H)))
    return N, (N*I_PK/(le_mm*1e-3))/79.577

# =============================================================================
# THE CHOSEN CORE - Magnetics Kool Mu toroid, core data 0254, from the
# catalogue page, not from the outside dimensions.
# =============================================================================
AL_0254 = {14:19, 19:26, 26:35, 40:54, 60:81, 75:101, 90:121, 125:168}  # nH/T^2
LE, AE, VE = 98.4, 107.0, 10600.0        # mm, mm^2, mm^3
OD, ID, HT = 40.77, 23.32, 15.37         # OD max, ID min, HT max

print("=== Geometry-derived Ae vs the catalogue, core 0254 ===")
Ae_est = ((OD-ID)/2)*HT
le_est = math.pi*(OD+ID)/2
print(f"  Ae  from dimensions {Ae_est:6.1f} mm^2   catalogue {AE:6.1f}"
      f"   {(AE/Ae_est-1)*100:+.0f}%")
print(f"  le  from dimensions {le_est:6.1f} mm     catalogue {LE:6.1f}"
      f"   {(LE/le_est-1)*100:+.0f}%")
print(f"  AL at 60u:  estimated {MU0*60*(Ae_est*1e-6)/(le_est*1e-3)*1e9:.0f} nH"
      f"   catalogue {AL_0254[60]} nH")
print("  The rounded edges cost 20% of Ae. That is turns, not a rounding error.")

print(f"\n=== Which permeability? (0254, {L_TARGET*1e6:.1f} uH at {I_PK} A) ===")
print(f"{'mu':>4} {'AL':>6} {'N':>4} {'H':>7} {'mu left':>8} {'dB':>7}"
      f" {'bundle max':>11} {'Cu':>7} {'P_cu':>7} {'Emax':>7}")
MLT = 54.3          # datasheet, winding length per turn at 20% fill
                    # (its 0% figure, 48.2, equals 2*(HT+(OD-ID)/2) exactly)
BUNDLE = 2.21                            # 3 x AWG18, twisted
for mu in (40, 60, 75, 90, 125):
    AL = AL_0254[mu]
    N, H = turns(AL, LE, mu)
    dB   = L_TARGET*DI/(N*AE*1e-6)       # T, peak-peak ripple flux density
    dmax = math.pi*ID/(N + math.pi)
    Lw   = N*(MLT + 2*BUNDLE)*1e-3
    R    = RHO*Lw/2.47e-6
    E    = (VE*1e-9)*1.0**2/(2*MU0*mu)
    print(f"{mu:>4} {AL:>5}n {N:>4.0f} {H:>5.1f}Oe {mu_frac(mu,H)*100:>7.0f}%"
          f" {dB*1e3:>5.1f}mT {dmax:>9.2f}mm {Lw:>6.2f}m {I_DC**2*R:>6.2f}W"
          f" {E*1e3:>5.0f}mJ")

print("""
  Note what did NOT decide this: DC bias. Every permeability lands at 80-85%,
  because higher mu needs fewer turns, which lowers H, which offsets the
  steeper roll-off curve. On a smaller core that trade goes the other way.

  What decides it is dB. Core loss scales roughly as dB^2.1 and Kool Mu's
  loss coefficient rises with permeability too, so the copper that 125u saves
  is paid back several times over in the core. Lower mu, lower dB, less loss.
  Check the vendor's loss curves for magnitude; the direction is not in doubt.

  => 0254 at 60u, 24 turns.""")

# =============================================================================
# The winding
# =============================================================================
print("\n=== Wire, for 24 turns on 0254 ===")
N60 = 24
d_max = math.pi*ID/(N60 + math.pi)
print(f"  I_rms {I_RMS:.2f} A ({I_DC:.2f} DC + {I_AC:.2f} AC)")
print(f"  fattest bundle that still gives {N60} turns in one layer:"
      f" {d_max:.2f} mm\n")

AWG = {14:(1.628,2.081), 16:(1.291,1.309), 18:(1.024,0.823),
       20:(0.812,0.518), 22:(0.644,0.326), 25:(0.455,0.162)}
print(f"{'winding':<14} {'Cu mm2':>7} {'bundle':>8} {'DCR':>8} {'P_dc':>7}"
      f" {'P_ac':>7} {'J':>6} {'fits':>6}")
for n, g in ((10,25),(5,20),(3,18),(2,16),(1,14)):
    ds, As = AWG[g]
    A   = n*As
    d   = 2*math.sqrt(A/0.75/math.pi)*1.08
    mlt = (MLT + 2*d)*1e-3
    R   = RHO*mlt*N60/(A*1e-6)
    rac = max(1.0, ds/(4*DELTA) + 0.25)
    print(f"{f'{n} x AWG{g}':<14} {A:>6.2f} {d:>6.2f}mm {R*1e3:>6.1f}mR"
          f" {I_DC**2*R:>6.2f}W {I_AC**2*R*rac*1e3:>5.0f}mW"
          f" {I_RMS/A:>5.1f} {'yes' if d<=d_max else 'NO':>6}")
# ---- core loss, from the datasheet's own figure ---------------------------
P100, B_REF, F_REF = 750.0, 100.0, 100e3     # mW/cm3 max at 100 kHz, 100 mT
def core_loss(dB_mT, f, Ve_mm3):
    return P100*((dB_mT/2)/B_REF)**2.1*(f/F_REF)**1.4 * Ve_mm3/1000 / 1000
dB60 = L_TARGET*DI/(24*AE*1e-6)*1e3
print(f"\n=== Core loss at 60u, 24 turns ===")
print(f"  datasheet {P100:.0f} mW/cm3 max at 100 kHz / 100 mT")
print(f"  ours: {dB60/2:.2f} mT peak at 200 kHz -> {core_loss(dB60, 200e3, VE):.2f} W")
Rw = RHO*(MLT*1e-3)*24/2.47e-6
print(f"  plus {I_DC**2*Rw:.2f} W copper = {I_DC**2*Rw + core_loss(dB60,200e3,VE):.2f} W total")

print("""
  P_ac is milliwatts everywhere, even solid AWG14 - the AC is 9% of the
  current, so skin effect is not what sizes this wire. Strand it because
  2.5 mm^2 of solid copper will not bend round the hole twenty-four times.

  => 3 x AWG18 twisted, grade 2 heavy build, Class 180 (H).
     Cut ~1.3 m per strand. Wind 25 turns, measure, remove one if it reads
     high - and do not pot it until it measures right.""")

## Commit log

2026-09-17 BenchSupply: printed enclosure for the bench power supply
    Forked from TritonECU/hardware/psu-enclosure as the version to grow: the
    supply is the first occupant, not the only one.
    Screw-down lid, 40 mm intake fan at one end, diamond exhaust grid at the
    other, fused IEC C14 inlet/switch module on a long side. External
    285 x 201 x 106, clear inside 279 x 156 x 79 for a 266 x 153 x 77 supply.
    Three decisions drove the geometry:
    - The lid screws cannot land in corner posts. With 3 mm of clearance beside
    the supply there is nowhere to put one, so the screws go into a band that
    thickens the wall inward around the top rim, sitting entirely above the
    supply where the volume is free. Its unde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
    [bench_supply.scad, lid.stl, tub.stl]
2026-09-18 The supply this box was built around is being replaced - write down what that means
    Two commits' worth of work, and the second half invalidates the first. Both
    are here because the reasoning in each is still worth having.
    ENCLOSURE. Ported the DC-DC module over from TritonECU, then moved the IEC
    inlet to END B and gave its terminals a printed shield:
    - On END B there is exactly one place the inlet can go - the bay's corner.
    Everywhere else the supply sits 3 mm behind that wall and 12 mm of flange
    plus 12 of booted terminals will not live in 3 mm. The grid occupies the
    supply's shadow, which is the part the inlet cannot use, so they do not
    compete.
    - It sits low because the shield s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
    [bench_supply.scad, lid.stl, shield.stl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]
2026-09-18 Specify the inductor core off the catalogue - and the catalogue moves the turns
    Core chosen: Magnetics Kool Mu toroid 0254, 60u, 22 turns of 3 x AWG18.
    The catalogue page corrected something the arithmetic got wrong. Ae worked
    out from the outside dimensions is 134 mm^2; the real figure is 107 - twenty
    percent less, because the rounded edges that stop the core cutting the wire
    take real iron away. That put AL at 100 nH instead of 81 and would have had
    this wound at 20 turns instead of 22. Geometry is fine for picking a size and
    not fine for winding one; core_choice.py now says so and works from the
    catalogue row.
    Two other things the numbers settled, both against what I first argued:
    - DC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
    [core_choice.py]
2026-09-18 Kool Mu Hf 0254 is a drop-in, and is not a reason to switch faster
    The Hf catalogue row for core 0254 is identical to the standard one wherever
    they overlap - 26u/40u/60u all at 35/54/81 nH, and le, Ae, Ve and the
    dimensions match too. So nothing in the design moves: same 22 turns, same
    3 x AWG18. Hf topping out at 60u costs nothing either, since 60u is where the
    dB argument already landed.
    Worth taking if it is stocked at a similar price - maybe 20-30% off the core
    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
2026-09-18 Mains to the back wall - the one surface with nothing on it, for a reason
    The back long wall was the only wall in the box with no holes, which is why it
    was the one to use, and exactly why it could not be used as drawn: the supply
    sat 3 mm behind it and the inlet reaches 24 mm inside with a shield over that
    needing 31.5. bay_back = 34 buys the room and leaves 2.5 mm to the supply.
    It is cheaper on a long wall than it was at END B. There the shield's 44 mm
    WIDTH had to fit across the bay, so the bay had to be 50. Here the width runs
    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
    [bench_supply.scad, lid.stl, shield.stl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]
2026-09-18 Double the floor to 6 mm - for stiffness, not strength
    5.8 kg of toroid is not much load. Even a 3 mm floor only sees 2.6 MPa against
    PETG's ~50 MPa yield, so stress was never the thing. Deflection is: at 3 mm
    the floor bows 2.1 mm under its own occupants, and a box standing on four
    rubber feet rocks on that. Creep then settles the bow in permanently, and a
    box shedding ~100 W runs warm, which speeds creep up.
    6 mm is 8x the stiffness (t^3) and a quarter of the stress (1/t^2) -> 0.27 mm.
    Costs ~200 cm^3 of envelope, 130-250 g depending on infill, and 3 mm of
    height: the box is now 285 x 243 x 109.
    docs/calc/floor.py has the plate arithmetic and a modulus sweep, since printed
    PETG is not a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
    [bench_supply.scad, lid.stl, shield.stl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]
2026-09-18 Control: the regulator keeps its own loop, the Pico only moves the divider
    docs/control.md, with docs/calc/control.py behind the numbers.
    The Pico is not a modulator and the reason is protection, not bandwidth. A
    180 W converter needs cycle-by-cycle current limiting inside ~100 ns - 2% of
    one 200 kHz cycle - and the RP2040 has no analog comparator and gets 2.5 ADC
    samples per cycle. Duty resolution at 9.3 bits is survivable; losing overcurrent
    protection is not. An analog TI/Maxim controller closes the loop; the Pico
    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
2026-09-18 Serial switches across the optos - and why not a digipot
    Confirms the chain: Pico SPI -> three optos -> serial-to-parallel on the
    isolated side -> switch array -> divider bottom leg.
    Better part for it than the 74HC595 I first wrote: an ADG714-class octal SPST
    is SPI-controlled analog switches in one package, so it IS the serial-to-
    parallel converter and the switch array. Ron ~2.5 ohm against a CD4051's ~100,
    which at the 1k end of the divider is 0.25% error instead of 10%. Two daisy-
    chained give 16 bits off the same three wires.
    Also recorded the thing NOT to do, since a serial digipot is the obvious
    simplification and it fails badly:
    at 60.0 V one tap moves it 9.705 V
    at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
    [control.py]
2026-09-18 Readback over the same optical barrier - SPI, and switch state comes free
    The Pico needs current, voltage and confirmation that the switch word it sent
    is the one that latched. All of it crosses optically, both directions: four
    outbound optos with their LEDs on the Pico side, one return opto with its LED
    on the isolated side. Nothing electrical bridges the gap, which is the point -
    these two channels get stacked in series.
    out: SCK, MOSI, CS_switches, CS_adc = 4 optos
    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
2026-09-18 One 5 V mains module for the control layer - and what it must not power
    5 V fans settle the aux supply: there is no 12 V rail in the box at all, and
    one off-the-shelf 120 V -> 5 V module runs the Pico, the fans and the opto
    LEDs. That removes the 12 V/5 V split the doc previously called for.
    Two things it does not cover.
    Size it at 10 W, not 5:
    Pico 100 mA
    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
2026-09-18 The 5 V module is open frame - the inlet's spades are not the only mains now
    Confirmed 5 V 3 A, 15 W, isolated, 100-264 VAC in. Against a 750 mA control
    load that is 4x headroom - past the "buy 10 W not 5 W" line, and enough to
    run 60 mm fans instead of 40s if the airflow check comes up short.
    The finding that matters is mechanical, not electrical. It is an OPEN FRAME
    board: live AC terminals and a live primary side on a bare PCB. Both the
    README and the .scad said the inlet's spade terminals were "the only exposed
    mains inside this box" and that is no longer true, so both are corrected. The
    module wants the same treatment as the inlet - a hood, or mounting inside an
    extension of the mains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
    [bench_supply.scad]
2026-09-18 Grid shell over the 5 V module, on the back wall - and the fuse wants to be 0.5 A
    The 5 V module is an open-frame board, so it gets a cover for the same reason
    the inlet's spades did. A GRID, not a solid hood: it is a switcher and a sealed
    box would cook it. Holes are 5 mm square, 7.07 across the corners against a
    12 mm test finger, and the .scad asserts that.
    Same two tricks as the mains shield, used twice over: open at the BACK so the
    enclosure wall closes it, open at the BOTTOM so the floor does, and wire slots
    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
    [bench_supply.scad, lid.stl, psu5_shell.stl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]
2026-09-18 Branch fuse for the 5 V module: 1 A time-delay
    Picked 1 A over the 0.5 A the arithmetic leans toward. It is 6.4x the module's
    156 mA maximum against 0.5 A's 3.2x - the looser end of sensible, and it will
    clear a hard short but not a partial failure drawing a few hundred milliamps.
    In exchange it is stocked everywhere in 5 x 20, which 0.5 A often is not.
    Time-delay either way: the module's input capacitor charges through the fuse
    at switch-on.
    The 3 A originally proposed stays in the table as the case that does not work
    - 19x rated draw cannot clear a fault in a 156 mA branch.
    [control.py]
2026-09-18 Temperature sensing: 1-Wire, and the isolation trap for the third time
    The deciding question is not which bus, it is where the sensors sit
    electrically. The temperature that matters is the pass-element heatsink; the
    FET tabs are switching nodes, so they mount on insulators and the heatsink is
    tied to its own channel's ground for EMI. Channel A's heatsink and channel B's
    are then at different potentials - 60 V apart once the channels are stacked.
    A metal-cased sensor bolted to each, both wired back to the Pico's ground,
    bridges the two channels. That is the third place the barrier can be given
    away by accident, after the setpoint divider and the control rail.
    Couple them thermally, isolate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
2026-09-18 Decided: the isolated side stays dumb, no per-channel MCUs
    Only switches, an ADC and a sense amp on the isolated side, doing what they are
    told over SPI. No firmware over there at all.
    "Offload the work" turned out not to be an argument because there is no work:
    bus occupancy is 14.4% and CPU occupancy, with SPI on DMA and 1-Wire on PIO, is
    under 1% of one of two cores. The DS18B20's 750 ms conversion is latency, not
    occupancy - issue the convert, go away, come back.
    (I had that wrong first pass and counted the conversion wait as CPU time, which
    made the Pico look 93% busy. Corrected before it reached a decision.)
    The real case for MCUs is recorded in case it is revisited: 2 optos per cha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
2026-09-18 Fans on the 2N7002 boards - keep the boards, swap the transistor
    The boards are the right shape and the wrong size. They were specified for
    14 mA into a DM542 optocoupler; a 5 V 40 mm fan is fifteen times that.
    fan current vs 115 mA rating Vds P in FET
    80 mA 0.7x 0.40V 32mW ok
    200 mA 1.7x 1.00V 200mW OVER RATING
    250 mA 2.2x 1.25V 312mW OVER RATING
    A SOT-23 sheds 200-350 mW at 25 C and far less in a box already shedding 100 W,
    and starting current is 2-3x running, so a 200 mA fan asks 400-600 mA at
    switch-on. The table is optimistic too: 5 ohm is the 2N7002 well enhanced, and
    a 3.3 V Pico GPIO doe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
2026-09-18 Clear a stale open item - sensor placement was settled in 5be5f32
    The control doc still listed "where the temperature is measured" as open after
    the 1-Wire decision resolved it. Removed.
2026-09-18 Spec the channels as a power envelope: 3 A to 50 V, 150 W ceiling
    Derating to a flat 2.5 A was the wrong shape of answer. The transformer does
    not care about amps, it cares about watts - 3 A at 12 V is 36 W and nothing to
    it - so a flat current derate threw away the bottom of the range for no reason.
    Vout I power
    12 V 3.00 A 36 W full 3 A
    40 V 3.00 A 120 W full 3 A
    50 V 3.00 A 150 W full 3 A
    55 V 2.73 A 150 W power limited
    60 V 2.50 A 150 W power limited
    3 A up to 50 V, tapering to 2.5 A at 60 V, 150 W per channel.
    Why 150 and not the 184 W one ST-1228 can just about give: at 3 A x 60 V the
    margin is 342 VA needed against 350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
    [control.py, core_choice.py, inductor.py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]
2026-09-18 Document the envelope properly - per channel, and stacked
    The six-row sketch became a real reference table: 2 V to 60 V in useful steps,
    with which limit is binding at each point. 3 A and current-limited up to the
    50 V corner, then 150 W and power-limited above it, down to 2.5 A at 60 V.
    Both channels can do the whole envelope at once, because each has its own
    transformer. Worth saying explicitly - it is the second thing the second
    ST-1228 buys, after the isolation.
    Added what the isolation actually gets you, which had not been written down
    anywhere:
    series : to 120 V, 3 A below 100 V, 2.5 A at 120 V (300 W total)
    +/- split: +/-60 V about a common centre
    parallel : to 6 A below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
    [power_budget.py]
2026-09-18 Controller chosen: LT8705, synchronous, and no junction in any path
    Analog Devices LT8705, one per channel. 2.8-80 V in, 1.3-80 V out, 100-400 kHz
    so 200 sits mid-range, quad N-channel drivers, and four servo loops - input
    voltage, input current, output voltage, output current.
    The 60 V output is what rules out the obvious parts, which was the trap flagged
    earlier and is now shown rather than asserted:
    LM5176 (TI) 4.2-55 V in, ~55 V out our 60 V is at or over the limit
    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
2026-09-18 The four switches: 100 V, 20-30 mOhm, and Qg is the binding parameter
    Sized from the operating points in docs/calc/fets.py rather than picked from a
    catalogue. Two results push against the instinct to buy the lowest Rds(on)
    available.
    Switch A carries the most current and does no switching. In boost mode the
    buck-side high side is simply held on, so it takes the full 6.02 A as pure
    I^2R, while C and D carry 4.3 and 4.2 A rms and take all the switching loss.
    One part number covers all four positions but they are not the same duty.
    And at 60 V, switching loss beats conduction loss:
    Rds A conducts t_sw C+D switching
    10m 0.36W 15 ns 1.08W
    25m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
    [fets.py]
2026-09-18 Fix an anchor left stale by renaming the CC heading
    Renaming "Current limit is analog too" to note the LT8705 already carries that
    loop broke the link pointing at it from within the same document.
2026-09-18 Core confirmed: Magnetics 0077083A7, DigiKey 4616-0077083A7-ND
    Datasheet committed to docs/datasheets/ because finding it was difficult, and
    the DigiKey number recorded because the search is the hard part here, not the
    decision. Note 083 is the ORDERING code, not the core-data number - the core
    data is 0254, and guessing the part number from it would have failed. Which is
    why it was not guessed.
    Every figure the design was built on matches exactly: 60u, AL 81 nH/T2, Ae 107,
    le 98.4, Ve 10,600, OD 40.77 / ID 23.32 / HT 15.37.
    Three things the datasheet added.
    The DC BIAS CURVE, which was the one figure still taken on trust: 80% of
    initial mu at 39 Oe and 50% at 87, both minimums, against t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
    [core_choice.py]
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2026-09-18 Soft start: a relay per transformer, and only one of them is firmware's
    design/schematic-mains.txt - the third schematic, and the one that resolves
    both the soft-start open item and the "inlet is now a distribution point"
    note. Inlet, three cartridge fuses, two soft-start stages, earth star.
    A 350 VA toroid's inrush is 10-100x its 2.92 A rating depending on where in
    the cycle you switch and on residual flux - up to 292 A. That is what welds
    switch contacts and trips breakers. A 10 R series resistor holds the first
    peak to 17 A and dissipates 85 W while it is in circuit: nothing as a 0.3 s
    pulse in a 20 W wirewound, fatal if it never ends.
    Which is the whole design. The two relays split alo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
2026-09-18 Two-stage soft start: soft relay then main, and the one-shot makes it safe
    Your arrangement, and it beats what I drew on two counts.
    L --+--[RLY_SOFT]--[ R ]--+-- primary
    | |
    +--[RLY_MAIN]---------+
    I had a series main with a parallel bypass across R. Both topologies have the
    same failure - one relay closes, the other does not, and R sits at 85 W - but
    only this one admits the fix:
    ** RLY_SOFT IS A 555 MONOSTABLE, ~300 ms, NOT A LEVEL. **
    It drops out by itself whether or not anything else worked. If RLY_MAIN never
    closes, the box is simply OFF - nothing burns, nothing to detect, nothing to
    recover from. The resistor can only ever be in circuit for on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
2026-09-18 BOMs for the three boards, and a design/README to hold them together
    bom-mains.csv (16), bom-rectifier.csv (9), bom-converter.csv (28), in the same
    eight-column format as the SEPIC work. One mains board, one rectifier and one
    converter per channel.
    Written through a CSV writer rather than by hand - the first pass had commas
    inside unquoted Notes fields and would not parse. All three now round-trip
    through csv.reader at 8 columns.
    The divider branch resistors are E96 nearest to the ideal binary conductances,
    with branch errors of 0.0-1.3%. That is deliberate rather than sloppy: the
    steps stay near-uniform, and the Pico reads its own output back through the ADC
    so it can calibrate code-to-vo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
    [bom-converter.csv, bom-mains.csv, bom-rectifier.csv]
2026-09-18 Control board: schematic and BOM - and the optos belong on the far end
    design/schematic-control.txt and bom-control.csv. All four boards are now
    drawn.
    The decision that shapes this board is where the optocouplers live, and it is
    NOT here. They go on the converter boards, one set per channel. Every signal
    leaving the control board is then Pico-referenced - the LED drive going out
    and the phototransistor collector coming back alike - and the isolation
    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
    [bom-control.csv]
2026-09-18 Fan 1 is staged like the others - TS1 is what makes that safe
    Correcting my own override. You specified all three fans staged on temperature
    and I substituted "hardwire fan 1 on" for the fail-safe, which threw away
    control you had asked for in order to buy a property that can be bought
    another way.
    A normally-open bimetallic thermostat in PARALLEL with fan 1's drive FET:
    FAN1 o----+-------[ AO3400 ]------- GND <- Pico, normal staging
    |
    +-------[ TS1 ]------- GND <- closes at 65 C regardless
    fan 1 on 35 C off 30 C
    fan 2 on 45 C off 40 C
    fan 3 on 55 C off 48 C
    TS1 closes ~65 C, opens ~55 C hardware, no firmware in the path
    TS1 sits A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
    [bom-control.csv]
2026-09-18 Expansion route: MCP23017 on the display's I2C bus, for zero pins
    Folding in your expander suggestion, with the I2C version rather than SPI
    because it costs nothing at all: the display is already on I2C and already
    costs 2 pins, so an MCP23017 at another address on the same bus adds 16 I/O
    for no additional GPIOs. It is also the part already running in TritonECU at
    0x20.
    The SPI version works - MCP23S17 can share SPI0's SCK/MOSI/MISO with the opto
    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
    [bom-control.csv]
